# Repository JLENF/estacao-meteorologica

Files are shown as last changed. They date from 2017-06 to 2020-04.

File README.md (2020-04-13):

# estacao-meteorologica
Projeto de uma estação meteorológica autossustentável desenvolvida inicialmente para o TCC na graduação de Engenharia Eletrica - FURB.

## Informações da publicação do TCC
[Biblioteca Universitária - FURB](https://bu.furb.br/consulta/portalConsulta/recuperaMfnCompleto.php?menu=rapida&CdMFN=363865)

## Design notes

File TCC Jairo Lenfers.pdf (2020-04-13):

UNIVERSIDADE REGIONAL DE BLUMENAU - FURB CENTRO DE CIÊNCIAS TECNOLÓGICAS DO DEPARTAMENTO DE

ENGENHARIA ELÉTRICA

CURSO DE ENGENHARIA ELÉTRICA

JAIRO EVANDRO LENFERS

ESTAÇÃO METEOROLÓGICA AUTOSSUSTENTÁVEL DE CÓDIGO ABERTO

BLUMENAU

2017

JAIRO EVANDRO LENFERS

ESTAÇÃO METEOROLÓGICA AUTOSSUSTENTÁVEL DE CÓDIGO ABERTO

Trabalho de conclusão de curso apresentado ao Curso de Graduação em Engenharia Elétrica do Centro de Ciências Tecnológicas da Fundação Regional de Blumenau, como requisito parcial para a obtenção do grau de Engenheiro Eletricista.

Prof. Sérgio H. Lopes Cabral – Orientador

BLUMENAU

2017

AGRADECIMENTOS

Primeiramente, agradeço a Deus, meu Pai Celestial, por ter me dado saúde e força para

superar as dificuldades ao longa da minha jornada, e que em todos os momentos é o maior

mestre que alguém pode ter.

A minha mãe, Iracema Isensee, a minha esposa, Jessica e ao meu filho, Arthur, pelo

extenso carinho e amor incondicional cedidos a mim ao longo de minha vida, guiando-me

sempre pelos caminhos do bem e despertando em mim a sede pelo conhecimento.
À Blunix Tecnologia, meu sócio Maicon e meus colaboradores, que por muitas vezes

trabalharam exaustivamente em minha ausência para que eu tivesse tempo para me dedicar

aos estudos.

Ao meu amigo Eduardo Maes, que por diversas vezes me mostrou as vantagens do

Software Livre e sempre me ajudou com suas ideias para melhorar meus projetos.

De forma especial agradeço ao meio orientador, professor Sérgio Henrique Lopes

Cabral, que me incentivou a continuar firme nos estudos e sempre acreditou no meu potencial,

pela atenção despendida e o suporte nas orientações e correções deste trabalho.

Aos meus amigos, Frederico Marks e Rafael Bruns, que no final da graduação

resgataram a minha vontade de estudar e me ajudaram nos estudos finais de semana para que

eu pudesse concluir esta graduação.

Aos meus colegas, amigos e professores do curso de Engenharia Elétrica, no qual

estivemos juntos nesta caminhada, pela companhia e amizade em todos os momentos.

A todas as pessoas que de alguma forma contribuíram para a realização deste trabalho.

Não cruze os braços diante de uma dificuldade,

pois o maior homem do mundo morreu de braços

abertos! (Autor desconhecido)

RESUMO

O uso de estações meteorológicas está cada vez mais comum, seja para uso agrícola, para utilizar as informações coletadas para tomadas de decisões ou até mesmo para hobby. O principal problema das estações meteorológicas comerciais é sua comunicação, que muitas vezes é offline, onde somente é possível visualizar as informações no local, e quando estas informações são online, utilizam protocolos fechados desenvolvidos pela própria empresa, sem compatibilidade com outros sistemas. A utilização desta estação inicialmente será focada com destino do uso em hobby em um clube de aeromodelismo, para ter informações das condições meteorológicas em tempo real antes de se deslocar para o local, pois dependendo do tempo, fica inviável a prática. Este trabalho trata desde a aquisição dos sinais recebidos pelos sensores até a transmissão pela internet possibilitando acessar de um aplicativo móvel. Serão utilizados sensores prontos, adquiridos na internet e apresentados detalhes do funcionamento destes individualmente. A pesquisa encontra-se em código aberto, possibilitando que outras pessoas reproduzam os métodos aqui descritos em sua totalidade e consigam contribuir com a melhoria deste projeto a fim de torná-lo cada vez melhor.

Palavras-chave: Estação meteorológica. Tecnologia. Internet das coisas. Arduino. ESP8266. Eletrônica.

ABSTRACT

The use of weather stations is frequently increasing, whether for the use in agriculture, for the use of information collected for decision making or even as a hobby. The main problem of commercial weather stations is its communication, which is often offline and only accessible in loco and, when this information is online, closed protocols developed by the company itself are used, not compatible with other systems. The use of this station will initially be focused for the use of a hobby at an aeromodelling club, in order to obtain weather information in real time before heading to the location since, depending on the weather it is unfeasible to practice the hobby under certain circumstances. This study begins with the acquisition of the signals received by the sensors to the transmission through the internet, allowing access from a mobile application. It will utilize ready for use sensors acquired from the internet and the operational details of these sensors will be presented individually. The research is an open source, enabling others to reproduce the methods described herein as a whole and to contribute to the improvement of this project in order to make it even better.

Key words: Weather station. Technology. Internet of things. Arduino. ESP8266. Electronics.

LISTA DE ILUSTRAÇÕES

LISTA DE ABREVATURAS E SIGLAS

INMET – Instituto Nacional de Meteorologia

mA – mili ampéres

A - ampéres

V - volts

VRLA (Valve-regulated lead-acid)

PWM - Pulse-Width Modulation

mm – milímetros

ADC – Conversor analógico para Digital

WiFi – Rede Wireless

SUMÁRIO

### 1 INTRODUÇÃO

As alterações climáticas estão recebendo mais atenção da mídia nesses últimos tempos

e se tornou um tema habitual em jornais, sites e revistas. As informações são repassadas,

algumas de maneira equivocada devido ao sensacionalismo das emissoras de televisão e

muitas vezes sem fundamento teórico.

A necessidade de obter informações das condições climáticas remotamente em pontos

específicos e em tempo real está se tornando cada vez mais comum. Com a imensa extensão

do nosso país e sua diversidade, uma informação sobre o tempo pode mudar completamente

em distâncias curtas. Por este motivo, dificilmente é possível utilizar uma informação

coletada em uma estação meteorológica instalada em um local distante do ponto em que é

preciso medir, pois podem sofrer alterações.

Com o uso de sensores adquiridos da internet, é possível desenvolver uma estação

meteorológica com comunicação pela internet. Os sensores vão captar os dados de

temperatura, umidade relativa do ar, direção do vento, velocidade do vento e intensidade da

chuva. Os dados dos sensores são processados por um microcontrolador e estão disponíveis

para serem acessados via internet de qualquer lugar do mundo, através de um aplicativo de

mensagem instantânea em aparelhos celulares.

1.1 HISTÓRICO MUNDIAL

Diante das mudanças climáticas do planeta, tais como o aquecimento global e o

derretimento das geleiras, acelerados pela ação humana, torna-se cada vez mais difícil prever

as mudanças climáticas. Em consequência disso, tem-se o aumento dos níveis dos oceanos,

desertificação, alteração do regime das chuvas, inundações e a redução da biodiversidade [1].

Estas alterações climáticas derivadas do aquecimento global são muito graves e podem

impactar profundamente o planeta. Estudos indicam que a temperatura global subiu 5ºC nos

últimos 10 mil anos - contados desde a última geração até 10 mil anos atrás – e pode aumentar

os mesmos 5ºC nos próximos 200 anos [2], mostrando que o aquecimento global é grande o

suficiente para que uma “pessoa na rua” perceba que o tempo está realmente mais quente [3].

1.2 HISTÓRICO NACIONAL

Não muito diferente do histórico mundial com o aquecimento global, o histórico

nacional tem mostrado o mesmo problema. Com uma diversidade climática imensa, extensão

territorial de 8,5 milhões de km, motivo ao qual é conhecido por “país tropical” [4]. A

diversificação do clima depende de muitos fatores tais como umidade, correntes marítimas,

ventos, pressão atmosférica, dentre outros. A Figura 1 representa o mapa do Brasil que mostra

os climas e suas diversidades.

Figura 1 – Climas no Brasil

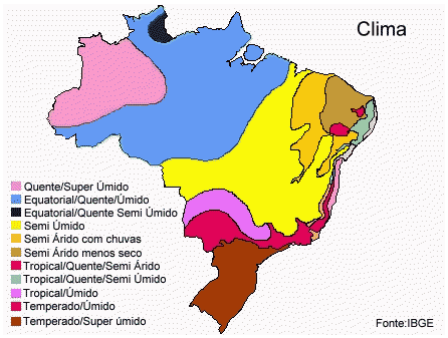
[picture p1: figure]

Fonte: IBGE [4]

Com estas diferenças climáticas entre as regiões, a informação do tempo de cada local

torna-se imprescindível para planejar a melhor colheita de determinado alimento utilizando

dados estatísticos, coletados nos anos anteriores.

Com a vinda dessas alterações pode-se notar diversos prejuízos econômicos, como a

crise que afeta diversos setores, físicos na estrutura das cidades e sociais na população. Tais

prejuízos são impostos em questão de minutos, horas, semanas mas levam anos para serem

restabelecidos.

Na região de Blumenau, Santa Catarina, tem-se históricos de chuvas abundantes em

determinados momentos, ocasionando enxurradas e enchentes. Estas chuvas ocorreram em

curto espaço de tempo e causaram bastante estragos [5]. Tais estragos poderiam ser menores

caso a população tivesse uma rede de estações meteorológicas interligadas, informando o

local exato e quantidade das chuvas. Desta forma, seria possível identificar onde a chuva está

ocorrendo exatamente e com qual intensidade. Com uma análise de dados, pode-se estipular

de onde e para onde estas chuvas estão indo e tomar certas decisões.

Muito embora haja estações meteorológicas instaladas, de modelos e diversos

fabricantes, cada uma destas estações trabalha com um protocolo diferente e não se

comunicam entre si. Além do fato de terem protocolos diferentes, muitas destas estações

passam por um tratamento de dados antes de ser apresentado ao público e algumas vezes com

certo tempo de atraso. Em alguns casos, as medições são feitas manualmente, onde um

profissional se encarrega de coletar os dados dos sensores e caso o acesso a este local esteja

comprometido, a medição também estará comprometida devido à dificuldade de chegar ao

local.

A medição exata do local em que se precisa da informação meteorológica também é

um fator decisivo. Atualmente existem no Brasil diversas estações meteorológicas instaladas,

porém, estão em locais específicos, determinados por critérios específicos do órgão que a

instalou. O Instituto Nacional de Meteorologia (INMET) possui atualmente 22 estações

meteorológicas instaladas no estado de Santa Catarina e somente duas estações estão

próximas à Blumenau conforme mostra a Figura 2.

Figura 2 – Estações meteorológicas do INMET em Santa Catarina

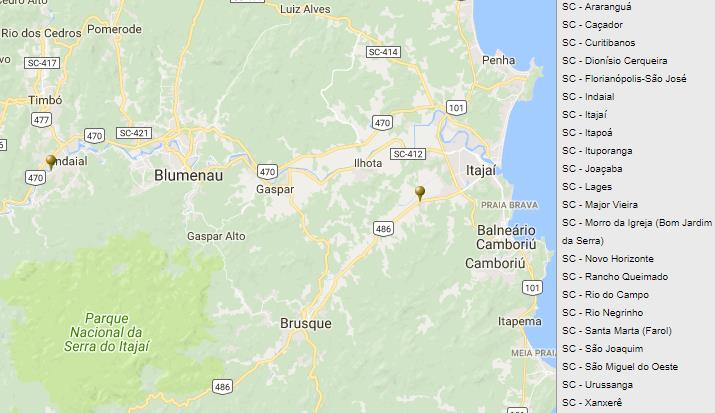
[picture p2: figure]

Fonte: INMET (2017) [6].

1.3. OBJETIVOS

1.3.1 Objetivo Geral

O objetivo geral visa pesquisar e desenvolver um projeto que atenda as

funcionalidades de uma estação meteorológica e que seja autossustentável de código aberto,

englobando o uso de sensores de alta precisão e baixo custo, aliados ao uso de tecnologias e

rede de transmissão dos dados, utilizando e mantendo todo o projeto com hardware e software

livre, para que outras pessoas possam desenvolver mais funcionalidades e agregar a este

projeto novas funções e possíveis correções.

O uso desta estação meteorológica tem a finalidade de atender a necessidade de um

clube de aeromodelismo em que faz necessário saber as informações meteorológicas em

ponto específico.

1.3.2 Objetivos Específicos

Para atingir o objetivo geral deste projeto, é preciso que alguns objetivos específicos

sejam estudados, tais como:

- O funcionamento dos sensores independentes (anemômetro, biruta,

temperatura e umidade do ar).

- Desenvolver o software do microcontrolador para receber as informações dos

sensores, processar estas informações e transmitir pela internet.

- Pesquisar a utilização de aplicativo específico para receber as mensagens com

informações coletadas pela estação meteorológica.

- Avaliar qual licenciamento utilizar para que este projeto fique disponível para

melhorias futuras e possível comercialização.

### 2 REVISÃO DE LITERATURA

Nesta revisão de literatura, serão abordados todos os itens que compõem uma estação

meteorológica tais como: o anemômetro que registra a velocidade e direção do vento, o

pluviômetro, que mede a quantidade de chuva em determinado período, sensores de

temperatura e umidade, abrigos seguros para estes sensores, dataloger que registra os dados

de vários sensores.

Como este trabalho tem o propósito de ser em código aberto, será abordado também

fundamentos do software livre e licenciamento aberto, que permite que outras pessoas possam

contribuir com este trabalho.

2.1 ANEMÔMETRO

Anemômetros são instrumentos utilizados para indicar a direção e medir a velocidade

do vento. Inspirado nos cata-ventos, eles são calibrados de forma que o total de voltas dadas

por suas pás correspondam a uma velocidade específica, ou seja, se no túnel de vento em que

foi calibrado a corrente do ar sopra a dez quilômetros por hora, e as pás giram cem vezes por

minuto, ele é programado para indicar 10 km/h sempre que o anemômetro atingir 100

rotações por minuto, e assim por diante [7].

O modelo de anemômetro mais utilizado é o modelo de copos (Anemômetro de

Robinson), mostrado na Figura 3, que utiliza três ou mais conchas montadas simetricamente e

é do tipo rotativo. A velocidade de rotação depende da velocidade do vento, não interferindo

em que direção ele chega no sensor. Geralmente utilizam um sensor magnético que conta o

número de voltas e de acordo com este número, é calculado a velocidade instantânea.

Figura 3 - Anemômetro

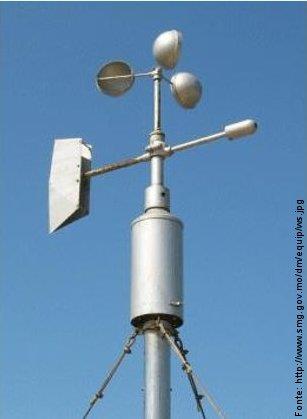
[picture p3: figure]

Fonte: CECHIN (2011). [7]

Acoplado a este anemômetro está o sensor de direção do vento. Este sensor funciona

com uma pá que mantem o “nariz” do sensor sempre apontado para frente, indicando a direção que o vento chega no sensor. É possível medir a velocidade do vento de duas formas

eletronicamente, com um potenciômetro ou com sensores magnéticos. A desvantagem de se

utilizar potenciômetro é sua vida útil e o possível arrasto que ele pode ter ao se movimentar.

2.2 PLUVIOMETRO

O pluviômetro é utilizado para medir em milímetros a quantidade de líquidos ou

sólidos, precipitados em determinado tempo e local [8].

Os modelos mais conhecidos, funcionam de modo que captam em um intervalo, a

quantidade de chuva precipitada, armazenando esta quantidade de chuva capturada em um

reservatório, conforme ilustrado na Figura 4. No final do dia ou no final da chuva, um técnico

especializado vai até o local para medir a quantidade de chuva no reservatório, funcionando

de forma totalmente manual.

Figura 4 – Pluviômetro manual

Fonte: HIDRAULIS [8].

Para entender como funciona a medição de um pluviômetro, é preciso saber como

funciona a unidade de medida de um pluviômetro.

Os pluviômetros registram as precipitações em milímetros (mm). O tanque

representado na Figura 5 possui uma área de base de 1m², se colocar 1 litro de água neste

tanque, se tem 1mm de água.

Figura 5 – Tanque demonstrando 1mm de água

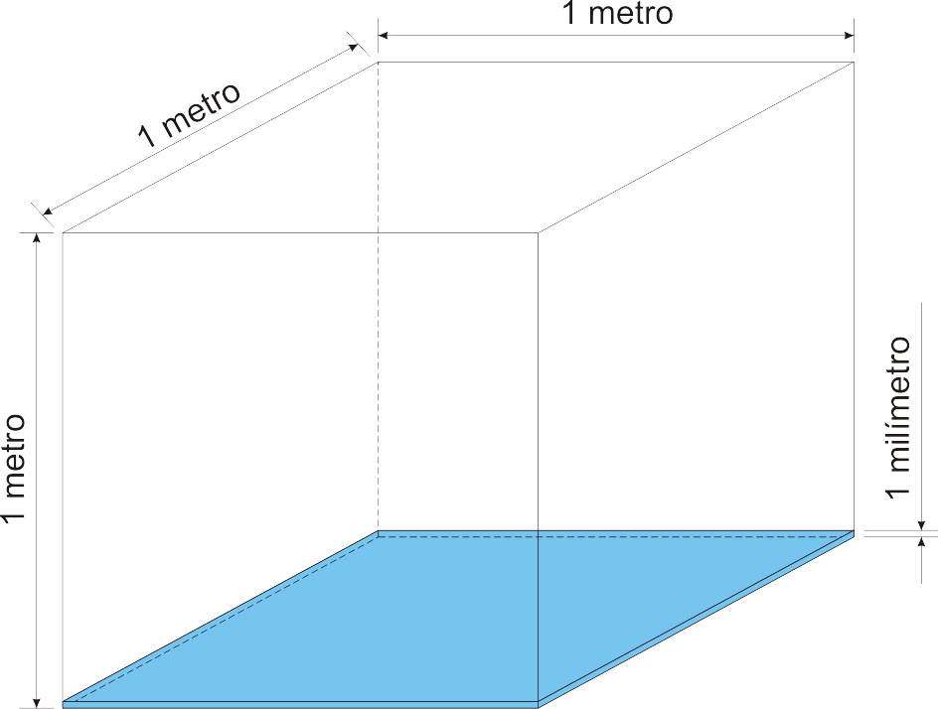
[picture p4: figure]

Fonte: MARTINS (2016). [9]

Da mesma forma é utilizado o pluviômetro manual, podemos descrever o pluviômetro

eletrônico, porém, ao invés de ter um reservatório para armazenar a quantidade de água

captada em um determinado período, ele possui um dispositivo chamado “gangorra” com dois

lados intitulado báscula, no qual, enche um pequeno reservatório e cada vez que este pequeno

reservatório enche, é enviado um pulso elétrico para o controlador efetuar a contagem [10].

De acordo com a quantidade de pulsos, é possível mensurar a quantidade de chuva precipitada

conforme mostrado na Figura 6.

Figura 6 – Pluviômetro eletrônico

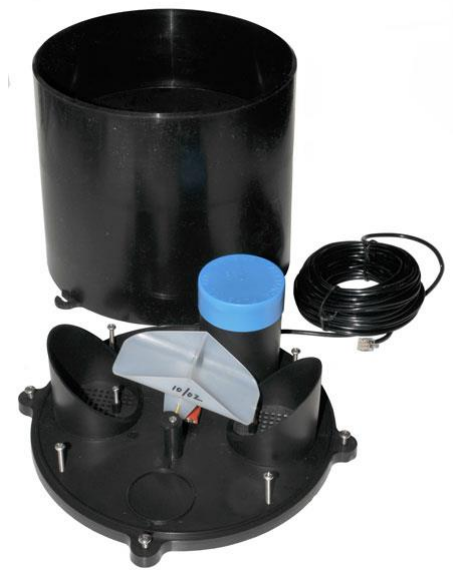
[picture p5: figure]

Fonte: BROOKE (2012). [11]

2.3 TEMPERATURA E UMIDADE DO AR

A temperatura pode ser medida com o uso de termômetros convencionais, que

fornecem um valor instantâneo desta variável. Em Meteorologia, termômetros convencionais

são do tipo liquido-em-vidro, cujo princípio de funcionamento se baseia na variação do

volume de um líquido apropriado, em resposta a uma mudança de temperatura do meio em

que está situado o instrumento. [12]

Termômetros não convencionais são os modelos que possuem sensores elétricos, que

são resistores com fio muito fino (cerca de 0,01 mm de diâmetro, cuja variação da resistência

elétrica causada pelo sensor é analisada por circuito eletrônico. A umidade relativa do ar

úmido, submetido a uma determinada temperatura, é o quociente entre a pressão parcial do

vapor e a pressão de saturação àquela temperatura. [12].

O sensor de temperatura e umidade geralmente vem em um único encapsulamento,

sendo que o mesmo sensor pode ser utilizado para efetuar as duas medições. A temperatura e

umidade do ar necessitam ser captadas por um sensor isolado e protegido, pois se o sol chegar

diretamente no sensor, pode interferir nos resultados, da mesma forma o sensor de umidade

que pode sofrer interferências com o orvalho que cai diretamente sobre ele. A umidade do ar

deve ser medida à sombra, em local ventilado e protegido da precipitação [13], motivo ao qual

é utilizado uma proteção para este sensor, mostrado na Figura 7.

Figura 7 – Sensor de temperatura e umidade

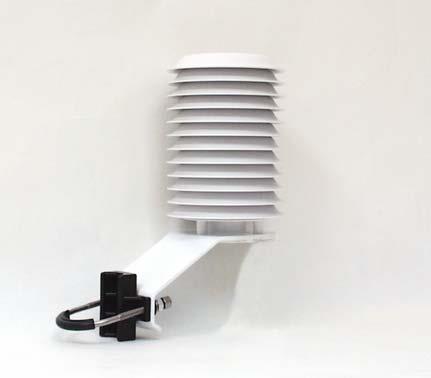
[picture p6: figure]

Fonte: CLEAN (2012). [14]

De acordo com a Organização Meteorológica Mundial (OMM) – entidade

internacional ligada à ONU que coordena as atividades operacionais na área das Ciências

Atmosféricas e estabelece normas e alturas padrões para instalação de equipamentos

meteorológicos – estes sensores de temperatura e umidade devem estar em uma altura entre

1,25 a 2,00 m acima do terreno e precisa ficar protegido [15].

2.4 DATA LOGGER

Data logger são aparelhos construídos de um micro controlador e memórias

específicas para armazenar determinados valores (Figura 8). Conseguem gravar uma série de

dados, dos diversos sensores das estações meteorológicas.

Muitas vezes, os gravadores de registros funcionam de forma offline, sem

comunicação com a internet, sendo possível visualizar as informações apenas estando no

local. Em outros casos, estas estações possuem um protocolo de comunicação próprio, onde

comunicam-se com um servidor na internet e enviam os dados de tempos em tempos para este

servidor próprio. Neste caso, as informações ficam em posse da empresa que desenvolveu esta

estação meteorológica, além de não saber se estas informações são utilizadas para outros fins,

não se tem garantia pois a empresa pode descontinuar o produto ou cobrar pelo serviço

futuramente.

Figura 8 – Data logger

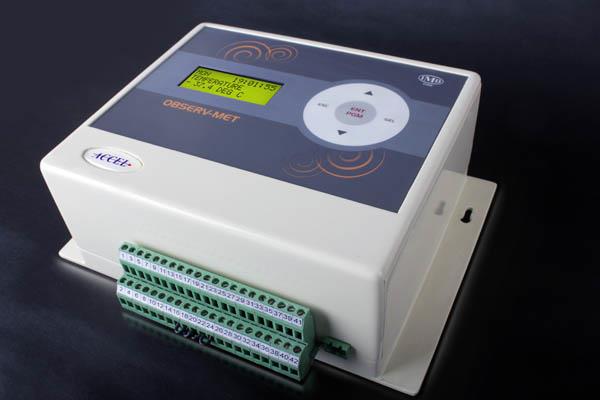
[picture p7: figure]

Fonte: ACCEL. [16]

2.5 SOFTWARE LIVRE

Um projeto, programa ou criação em geral pode ser licenciado de várias formas,

dentre elas licenciamento fechado ou aberto. Neste trabalho, é utilizado o licenciamento

baseado em código livre ou código aberto, que significa que todo seu conteúdo, seja os

códigos, desenhos, projetos, podem ser reproduzidos, copiados, alterados e comercializados.

Esse tipo de licença foi idealizado por Richard Stallman, que criou a Free Software

Foundation [17].

O software livre deve possuir quatro liberdades fundamentais e essenciais:

0 – executar o programa;

1 – acesso ao código fonte (open source = código aberto): estudar como ele

funciona e adapta-lo às suas necessidades;

2 – distribuir cópias livremente;

3 – melhorar o programa e liberar seus aperfeiçoamentos, para que toda

comunidade se beneficie.

A licença utilizada neste trabalho é a Massachusetts Institute of Technology (MIT) que

tem a seguinte característica:
- É possível usar, copiar e modificar o software pois não tem impedimento de uso o

que possibilita utiliza-lo em qualquer projeto (inclusive proprietários);

- Permite a distribuição gratuita e venda sem restrições;
- A única exigência é que o produto deve ser acompanhado com a licença.

Dentre as inúmeras vantagens do software livre, é possível ressaltar que o usuário

pode ter acesso ao código fonte do programa, contribuir com a melhoria do código ou até

mesmo entrar em contato diretamente com o desenvolvedor do software para esclarecer

dúvidas, avisar sobre falhas no sistema ou sugerir melhorias, resultando em uma agilidade no

processo de correção e melhorias. Vantagens estas que não se encontra em software

proprietários e dificilmente consegue-se entrar em contato diretamente com o desenvolvedor,

direcionando a solicitação para a equipe de suporte e que podem demorar até que cheguem ao

desenvolvedor.

Um exemplo clássico de uso em software livre é o sistema operacional Linux, gratuito,

desenvolvido por Linux Torvalds com a ajuda de milhares de programadores em todo mundo,

por se tratar de um sistema operacional de código aberto. Em contrapartida, o sistema

operacional Windows de propriedade da Microsoft ® é um sistema de código fechado, onde

somente os funcionários da empresa mantém as atualizações das funcionalidades do seu

sistema operacional.

Desta forma, utilizando o licenciamento de código aberto, este trabalho poderá sofrer

alterações e melhorarias, pois, o movimento do software livre tem como filosofia ser

colaborativo, que permite as pessoas contribuírem em áreas específicas, aprimorando a ideia

central do projeto.

### 3 PROPOSTA

Quando se fala em estações meteorológicas tem-se a ideia apenas das condições

meteorológicas de forma geral. Todavia, é possível utilizá-las para outros fins como meio de

informação do ambiente, principalmente em locais específicos. Tais necessidades são

utilizadas para trabalho ou para hobby.

A ideia de uma estação meteorológica surge a partir de um hobby praticado aos finais

de semana, o aeromodelismo, que depende da velocidade e força do vento, dependendo das

condições meteorológicas o vôo torna-se impossível. Outro exemplo são as atividades de asa

delta ou parapente, a rampa de salto é direcionada para um local e caso o vento não esteja em

direção contrária, impossibilita o vôo. Os praticantes destes esportes têm que se deslocar até o

local para a prática da atividade e muitas vezes acabam demorando para chegar, para constatar

que o vento não está de acordo. Utilizando os dados de outras estações meteorológicas, não se

consegue as informações precisas do local do vôo e mudam muito de local para local.

Na imagem seguinte, é apresentado um exemplo de local para ser instalado a estação

meteorológica. O Clube de Aeromodelismo Asas do Vale (Figura 9), permite a decolagem e

pouso dos aeromodelos que são feitos com o vento preferencialmente paralelo à pista. Caso o

vento esteja perpendicular à pista, é conhecido como vento de través e necessitam de certa

habilidade para pousar.

Figura 9 – Clube de aeromodelismo Asas do Vale em Gaspar

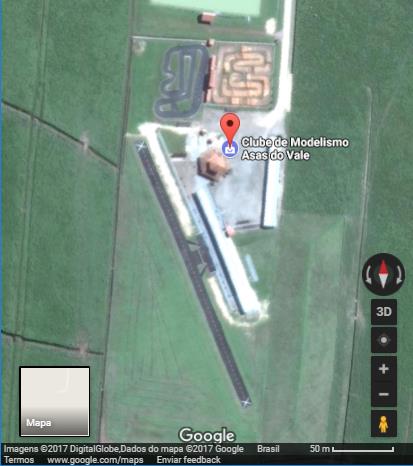
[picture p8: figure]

Fonte: GOOGLE (2017). [18]

Com base em conversas dos praticantes de aeromodelismo no clube citado,

historicamente tem-se os registros que aos sábados e domingos, o vento está paralelo à pista

somente até o horário 12h00. Geralmente a tarde o vento está de través e acontecem alguns

incidentes por conta disto. A comunicação dos sócios que estão no clube com os sócios que

estão para ir ao clube geralmente são de como está o vento e se está chovendo, conforme a

Figura 10.

Figura 10 – Exemplo troca de informações sobre o tempo local

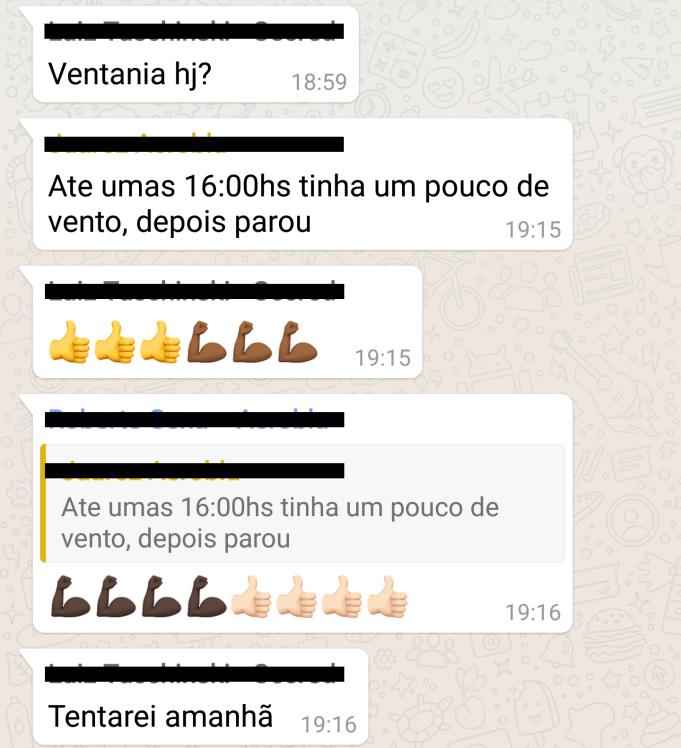
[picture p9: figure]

Fonte: O autor (2017).

Outro problema é mensurar a velocidade do vento, o que é forte para alguns pode ser

fraco para outros, dependendo da habilidade de cada piloto. Por isso é importante uma estação

meteorológica no clube para que cada piloto acompanhe em tempo real a velocidade e direção

do vento para que se sinta mais seguro em voar.

Além das informações de velocidade e direção do vento, é importante incluir um

pluviômetro para medir a quantidade de chuva que caiu no local, um sensor de temperatura e

umidade para registar as variações de temperatura, um sistema de transmissão dos dados e um

sistema de carregamento solar, para que funcione de forma autônoma. Desta forma, a estação

meteorológica poderá ser utilizada não somente nos clubes de aeromodelismo e voo livre, mas

também em outras aplicações em que requerem uma exatidão na informação de meteorologia,

tais como fazendas para ter um controle mais específico das safras.

### 4 DESENVOLVIMENTO

O desenvolvimento da estação meteorológica autossustentável se divide em vários

módulos conforme é mostrado no diagrama de blocos na Figura 11. Irá contar com vários

assuntos relacionados ao curso de Engenharia Elétrica como: geração de energia,

armazenamento de energia, análise e processamento dos sinais dos sensores, conversão de

dados, processamento em tempo real e transmissão das informações via internet para um

dispositivo móvel (celular).

Figura 11 – Diagrama de blocos

Fonte: O autor (2017).

Geração de energia: Este projeto conta com geração de energia solar com um módulo

que vai regular a tensão recebida pela placa solar e gerenciar o carregamento da bateria.

Armazenamento de energia: A estação utiliza uma bateria para que o sistema funcione

de modo offline quando a geração solar não for suficiente ou em períodos noturnos.

Análise e processamento dos sinais dos sensores: Esta estação conta com diversos

sensores de diversos tipos. Nem todos contam com a mesma interface e o mesmo protocolo de

comunicação. O projeto em questão vai abordar a forma de comunicação e protocolo destes

sensores.

Processamento em tempo real: Muitas vezes um determinado microcontrolador não

consegue atender todas as necessidades de certo projeto. Entradas e saídas são fundamentais.

A escolha entre custo e benefício é essencial. Este projeto conta com um micro controlador

que atenda estas necessidades.

Transmissão de dados via internet: Praticamente uma das partes mais importantes

deste trabalho é a comunicação online da estação meteorológica com dispositivos móveis.

4.1 MODULO SOLAR

A captação de energia é exclusivamente de forma solar, portanto a escolha de um

painel que atenda às necessidades deste projeto de forma adequada é essencial. Mediante a

medição do consumo elétrico médio do circuito, chegou-se no valor de 100mA x hora, logo,

precisa-se de um painel que forneça energia suficiente para alimentar o projeto e carregar as

baterias. O módulo solar escolhido foi o silício policristalino [19] com dimensões de

147x147mm, tensão de 12 volts e corrente nominal de 250 mA x hora por placa.

Para garantir o correto funcionamento, são utilizados quatro painéis em paralelo, para

os dias em que a geração solar não estiver no seu valor necessário. As quatro placas solares

montadas em seu suporte são mostradas na Figura 12.

Figura 12 – Placa solar

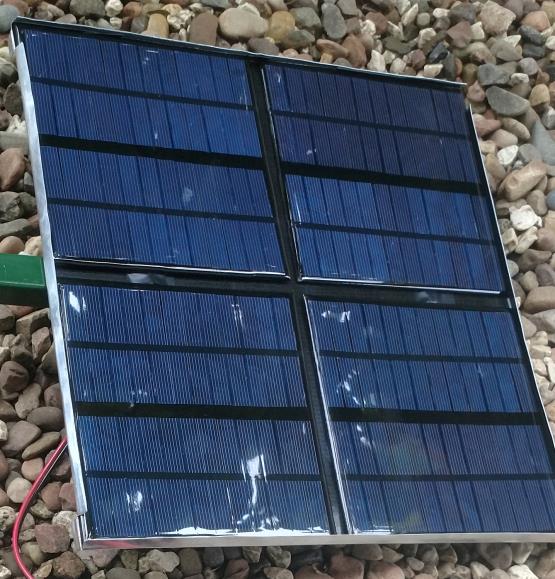
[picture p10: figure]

Fonte: O autor (2017).

4.2 CARREGADOR SOLAR

A energia captada pelas placas solares não pode ser injetadas diretamente na bateria,

para que não haja sobrecorrente e não danifique as baterias, assim, optou-se por utilizar um

gerenciador de energia solar [20], com função para carregar as baterias conforme ilustrado na

Figura 13. O modelo escolhido foi o SX01-3A com saída de 3 amperes.

Dentre suas especificações, as características abaixo são importantes para este projeto:

- Compatibilidade com bateria VRLA;
- Proteção contra sobrecarga da bateria;
- Chaveamento automático entre a célula solar e a bateria, de acordo com a

intensidade do sol;

- Controle de carregamento PWM, que garante eficiência de 3% a 16% maior que

os carregadores não-PWM;

- Proteção do painel solar contra curto circuito.

Figura 13 – Carregador solar

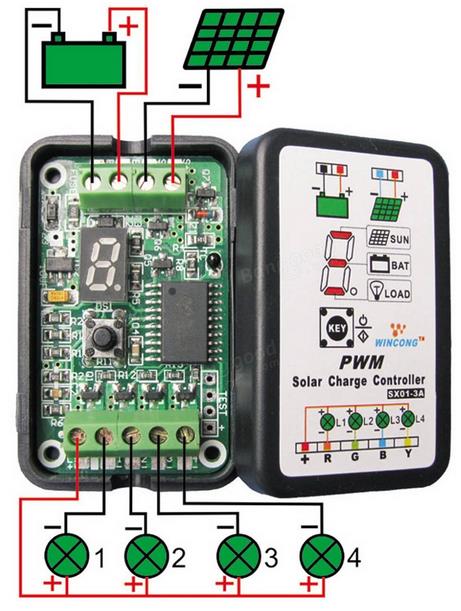
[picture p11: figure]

Fonte: ALIEXPRESS. [20]

4.3 ARMAZENAMENTO DA ENERGIA – BATERIA

A bateria escolhida para alimentar este projeto quando a geração de energia solar não

for suficiente é a bateria VRLA (Valve-regulated lead-acid), também conhecida como bateria

selada de chumbo ácido, que é livre de manutenção.

Por ser selada, pode ser utilizada em ambientes fechados pois não libera produtos

nocivos. Como a saída da célula solar é de 12v, optou-se por utilizar uma bateria de 6v. Outra

vantagem de se utilizar bateria de 6v é não precisar de um regulador externo para adequar a

tensão para o microcontrolador, uma vez que o regulador interno funciona muito bem com

esta tensão.

A capacidade escolhida foi de 12 amperes / hora, que devido ao baixo consumo do

projeto permite o uso do sistema por aproximadamente 120 horas, levando em conta um

consumo de 100mA / hora. A imagem da bateria é mostrada na Figura 14.

Figura 14 – Bateria VRLA 6v 12a

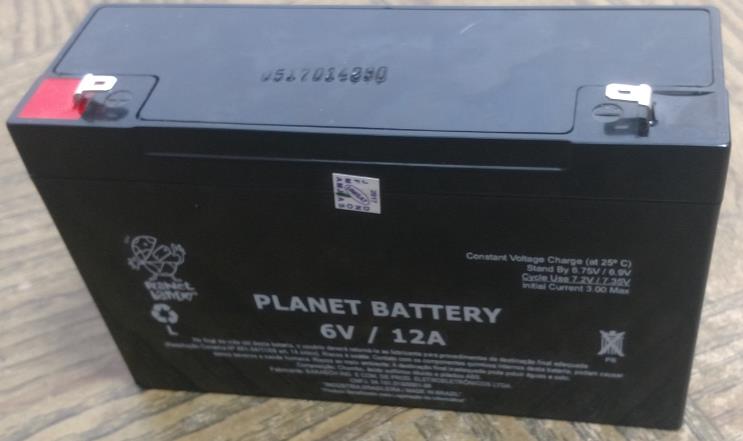
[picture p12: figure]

Fonte: O autor (2017).

4.4 ANEMÔMETRO

Este sensor possui a finalidade de medir a velocidade do vento, utilizando um sensor

magnético do tipo reed switch, que ao entrar em contato com um elemento magnético (imã),

fecha os seus contatos, deixando fluir a corrente elétrica entre seus terminais.

Para medir a velocidade do vento, é utilizado um sistema do tipo conchas, que capta a

velocidade do vento e transforma em movimento mecânico. Por um sensor magnético na base e um elemento magnético na parte superior, é possível mensurar a velocidade em que o sensor

está girando. Cada volta do sensor é enviado um pulso elétrico para o micro controlador, e

este fará a contagem. A parte interna do sensor juntamente com o sensor magnético é

mostrado na Figura 15 e a parte superior mostrando o imã é mostrado na Figura 16.

Figura 15 – Anemômetro velocidade do vento – parte interna

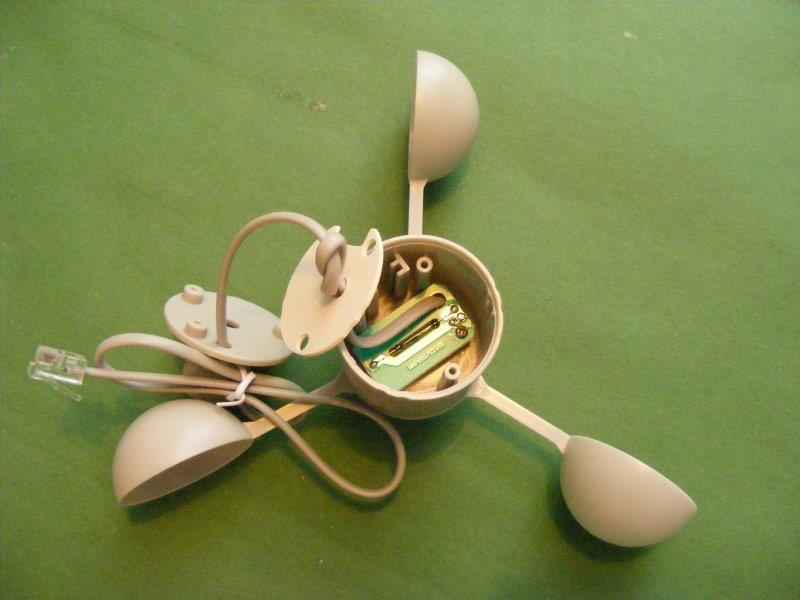
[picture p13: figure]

Fonte: PHOTOS. [21]

Na parte superior do anemômetro que mede a velocidade do vento, tem-se um

elemento magnético que ao completar uma volta completa, entra em contato as duas

extremidades do sensor magnético, enviando um pulso elétrico para o micro controlador e

assim registrando sua velocidade.

Figura 16 – Anemômetro velocidade do vento – parte superior

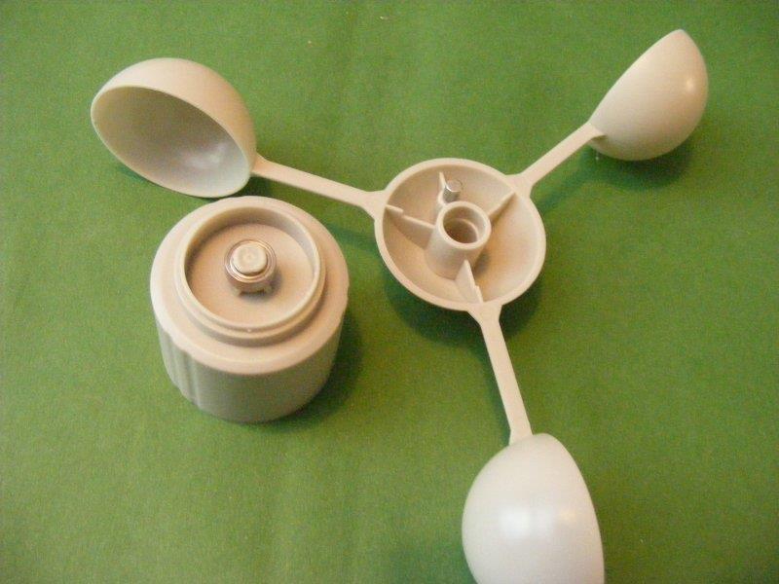
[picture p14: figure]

Fonte: PHOTOS. [21]

4.4.1 Esquema elétrico

O esquema elétrico para o funcionamento do anemômetro pode ser visto na Figura 17,

com o reed switch e um resistor de 10k push up, que mantém uma resistência com a tensão

positiva evitando que a entrada do sinal flutue entre o positivo e terra, enquanto o sensor não

está com o pulso do sinal.

Figura 17 – Esquema elétrico anemômetro

Fonte: O autor (2017).

4.4.2 Calibração

A calibração do anemômetro, consiste em uma constante definida pelo fabricante. São

efetuados testes em túneis de vento com o anemômetro e é definido o valor de uma constante

para cada modelo de anemômetro. Esta constante é multiplicada na fórmula dentro do micro

controlador para mensurar a velocidade correta do anemômetro. Pode-se aferir a velocidade

de um anemômetro utilizando outro anemômetro comercial.

4.4.3 Código

Para o funcionamento do anemômetro, foi configurado o microcontrolador para

acionar uma função (Contador Anemometro) quando houver uma interrupção na porta digital

em que o anemômetro está conectado. Cada vez que houver uma interrupção, é adicionado

um valor em uma variável (numRevsAnemometro). Após um período pré-determinado

(PERIODO_ANEMOMETRO), o microcontrolador calcula quantas voltas houve no

anemômetro | neste | período | e | multiplica | pela | constante | de | calibração

(CTE_CAL_ANEMOMETRO), para determinar a velocidade do mesmo.

4.5 BIRUTA ELETRÔNICA

Para detectar a direção do vendo, é utilizado o mesmo princípio do sensor anterior

utilizando sensores magnéticos do tipo reed switch, juntamente com um guia que manterá o

“nariz” do sensor sempre para frente indicando a direção em que o vento chega no sensor

conforme mostra a Figura 18.

Figura 18 – Biruta direção do vento

Fonte: PCE. [22]

Neste sensor é utilizado oito sensores magnéticos conforme mostrado na Figura 19 e

apenas um elemento magnético (imã) fixado na parte superior do sensor representado pelo

círculo vermelho. De acordo com a posição do ponteiro, vai entrar em contato um resistor de

determinado valor que vai mensurar a posição que se encontra atualmente.

Figura 19 - Orientação bússola

Fonte: O autor (2017).

4.5.1 Esquema elétrico

O esquema elétrico da biruta eletrônica pode ser conferido na Figura 20, com oito reed

switch ligados alimentados por uma tensão de 3,3volts em paralelo com oito resistências de

10k, e são lidos na porta analógica do micro controlador.

Figura 20 – Esquema elétrico – Biruta eletrônica

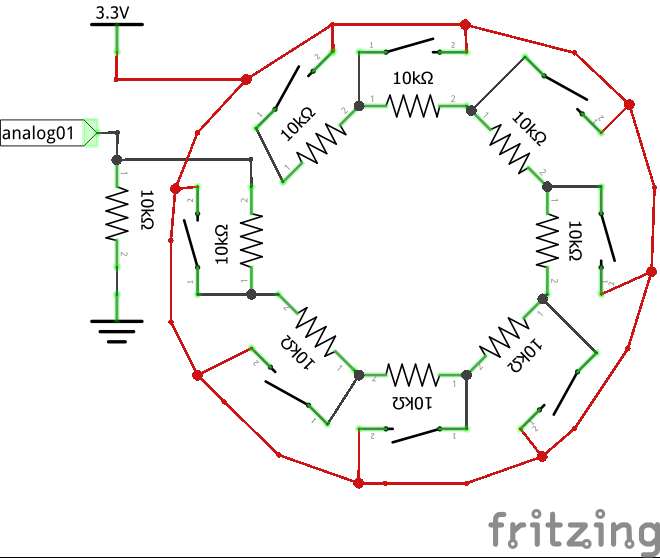
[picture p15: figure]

Fonte: O autor (2017).

4.5.2 Calibração

De acordo com a posição da biruta, o sensor vai fechar uma resistência e como estão

em série, os valores podem ir de 10k a 80k. O Norte foi arbitrado que está posicionado no

primeiro resistor de 10k e foi identificado no sensor para quando instalar no local, alinhar corretamente com o Norte. Foi utilizado um resistor externo de 10k como divisor de tensão e

foi medido a tensão de saída conforme mostra o Quadro 1 para conectar na porta do conversor

analógico / digital do micro controlador.

Quadro 1 – Relação de resistência em relação à posição do anemômetro

Direção (ângulo) | Resistencia (Ohms) | Tensão (V=3,3v, R=10k) | Valor ADC
0º - N | 10k | 1,63v | (335 a 327)
45º - NE | 20k | 1,09v | (207 a 194)
90º - E | 30k | 0,82v | (151 a 139)
135º - SE | 40k | 0,65v | (115 a 105)
180º - S | 50k | 0,54v | (91 a 84)
225º - SO | 60k | 0,47v | (77 a 72)
270º - O | 70k | 0,41v | (68 a 63)
315º - NO | 80k | 0,36v | (61 a 58)

Fonte: O autor (2017).

4.5.3 Código

Para detectar a posição da biruta, foi conectada ao microcontrolador na porta analógica

e utilizando a função “analogRead”, que converte os valores das tensões em valores digitais.

De acordo com o valor digital medido e mostrado no Quadro 1 acima, é possível detectar a

posição em que se encontra a biruta eletrônica.

4.6 SENSOR TEMPERATURA E UMIDADE DO AR

O sensor de temperatura e umidade utilizado foi o modelo DHT22 que possui saída

digital calibrada. Ele utiliza um sensor capacitivo de umidade e um termissor para medir a

temperatura do ar. Possui tamanho compacto, baixo consumo e alta precisão.

O sensor DHT22 consegue medir temperaturas de -40º a 80º Celsius, e umidade na

faixa de 0 a 100%. Sua precisão para temperatura é de 0,1º e para umidade de 0,1%. Na

Figura 21 verifica-se a pinagem de ligação deste sensor e o datasheet encontra-se no link [23].

Figura 21 – Sensor temperatura e umidade DHT22

Fonte: FILIPEFLOP (2017). [24]

4.6.1 Esquema elétrico

O sensor DHT22 possui um microcontrolador de 8bits que produz um sinal digital no

pino de dados, facilitando a comunicação com o microcontrolador. O fabricante fornece uma

biblioteca de código aberto para comunicação entre o sensor e o microcontrolador. A ligação

deste sensor é relativamente simples devido ao sinal já vir pronto, ilustrado na Figura 22.

Figura 22 – Esquema elétrico DHT22

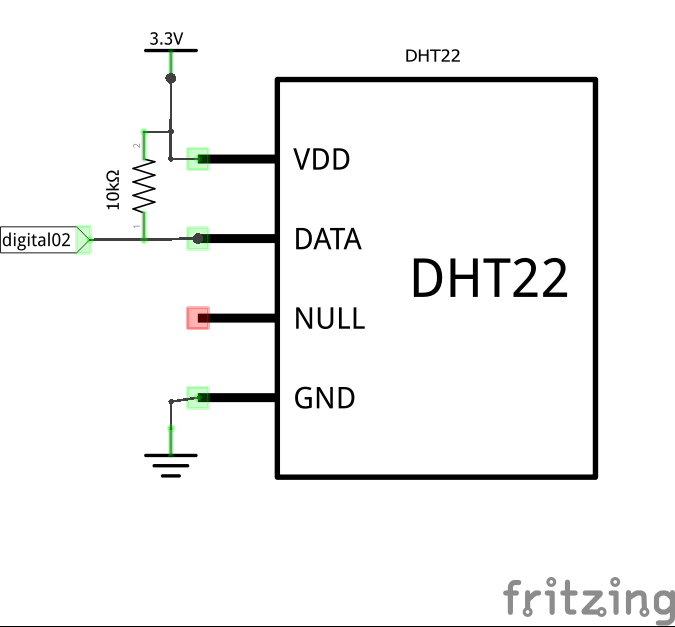
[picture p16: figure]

Fonte: O autor (2017).
4.6.2 Calibração

Por possuir um microcontrolador interno que interpreta os sinais do termissor e do

sensor capacitivo de umidade, este sensor dispensa calibração, pois contém seu encapsulamento fechado e inacessível. O único item que pode interferir na medição deste

sensor é ele ficar exposto diretamente ao sol, que pode interferir nas medições. Por isso foi

adquirido um abrigo especialmente desenvolvido para sensores de temperatura, que contem

aletas que permitem a circulação do ar sem que tenha contato direto com o sensor conforme

mostra a Figura 23.

Figura 23 – Abrigo sensor temperatura

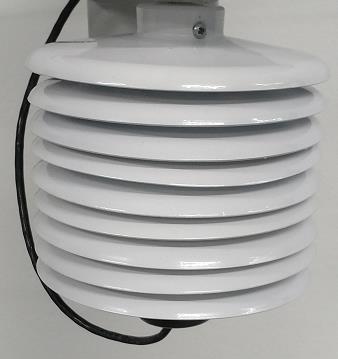
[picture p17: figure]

Fonte: O autor (2017).

4.6.3 Código

O código para funcionamento deste sensor foi fornecido pelo fabricante (DHT.h) com

todas funções necessárias para a comunicação deste sensor. Basta definir o tipo de sensor

utilizado (#define DHTTYPE DHT22), informar o pino em que o sensor está conectado ( ) e

inicializar o sensor (DHT dht(DHTPIN, DHTTYPE, 11);). Após estas configurações, foi

programado para chamar a função necessária para ler a temperatura instantânea

(dht.readTemperature()) e para ler a umidade relativa do ar (dht.readHumidity()).

4.7 PLUVIÔMETRO

O funcionamento do pluviômetro baseia-se em um funil que capta uma área e

direciona a chuva captada para uma báscula que ao receber água e transborda, movimenta-se

como uma gangorra, fechando os contatos de um sensor magnético fazendo fluir um pulso

elétrico para a entrada do microcontrolador. Cada pulso do sensor indica uma mudança de estado da báscula registrando aquela quantidade em milímetros, que é a unidade padrão de

precipitação. A Figura 24 mostra a parte superior do pluviômetro com o funil para capturar a

chuva e a Figura 25 mostra o interior de um sensor pluviométrico, com a báscula e o elemento

magnético.

Figura 24 – Parte superior do pluviômetro

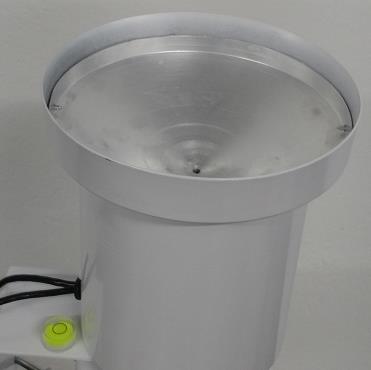
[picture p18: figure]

Fonte: O autor (2017).

Figura 25 – Interior do pluviômetro

,

Fonte: O autor (2017).

4.7.1 Esquema elétrico

O esquema elétrico para o funcionamento do pluviômetro é idêntico ao esquema

elétrico do anemômetro, com o reed switch e um resistor de 10k push up que pode ser visto na

Figura 26, que mantém uma resistência com a tensão positiva evitando que a entrada do sinal

flutue entre positivo e terra, enquanto o sensor não está com o pulso do sinal.

Figura 26 – Esquema elétrico pluviômetro

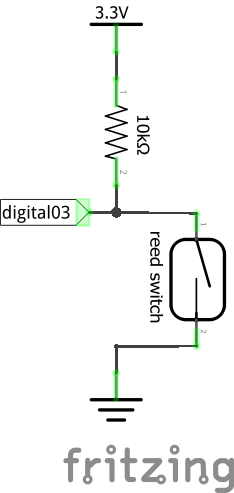
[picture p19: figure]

Fonte: O autor (2017).
4.7.2 Calibração

A calibração deste sensor conta com uma constante fornecida pelo fabricante, onde

cada báscula cheia de água muda o estado da gangorra e representa uma quantidade de chuva

captada por um pequeno reservatório. O valor fornecido pelo fabricante deste pequeno

reservatório é de 0,25mm por batida de báscula.

Pode-se aferir este valor, utilizando o método [25] descrito abaixo:

- A boca do funil que capta a chuva possui um raio de 73mm.
- Área da boca do funil = π * r² = 167,33 cm² ou 0,016733m²
- Quantidade de batidas da báscula com 500 ml de água = 67

C_b = V / ( B * A) = 0,5 l / (67 batidas * 0,016733 m²) = 0,4459 mm ≅ 0,45 mm onde C_b é a quantidade de chuva por batida de báscula, V é o volume de água

derramada, B é a contagem de batidas por cada 500 ml e A é a área da “boca” do

pluviômetro.

Para uma melhor aferição do valor medido, é utilizado um regador com a quantidade

de água citada acima, simulando uma queda de água livre igual as chuvas.

Com este experimento, podemos concluir que o volume de água por batida de báscula

é diferente do valor fornecido pelo fabricante e como este projeto foi programado para aceitar

um valor de calibração, após efetuar testes com aparelhos com maior precisão, poderá ser

alterada esta constante de calibração.

4.7.3 Código

O pluviômetro possui código semelhante ao anemômetro, onde foi configurado o

microcontrolador para acionar uma função (contadorPluviometro) quando houver uma

interrupção na porta digital em que o pluviômetro está conectado. Cada vez que houver uma

interrupção, é adicionado um valor em uma variável (numBatidasBascula). Após um período

pré-determinado (PERIODO_PLUVIOMETRO), o microcontrolador calcula quantas batidas

de báscula houve no pluviômetro neste período e multiplica pela constante de calibração

(CTE_CAL_PLUVIOMETRO), para determinar quantos milímetros choveu naquele instante.

4.8 MICRO CONTROLADOR

Este é um dos itens mais importante do projeto, o microcontrolador ESP8266 que está

incorporado em uma placa de desenvolvimento NODEMCU ESP-12E. Será executado o

programa principal que vai se comunicar com os sensores, conectar na internet e enviar os

dados para os dispositivos móveis. O código fonte completo do microcontrolador ESP8266

para funcionamento desta estação está no Anexo I.

Dentre as inúmeras vantagens de se utilizar este micro controlador, podemos citar

algumas que são muito importantes para este projeto:

-Compatibilidade com código e bibliotecas do Arduino;

-Microprocessador ARM de 32 bits;

- Suporte integrado para Rede WIFI;
- Antena WiFi embutida, já soldada na placa (livre de mal contatos);
- Compatível com IDE do Arduino;

- 10 entradas digitais GPIOs operando a 3,3V
- 1 entrada analógica GPIO a 1,8 V;
- Baixo custo;
- Tamanho reduzido da placa;
- Baixo consumo de energia;
- Temperatura de trabalho: -40 ℃ ~ +125 ℃;
- Alimentação: 4.5V ~ 9V (10VMAX), USB-powered.

A maior vantagem de utilizar este microcontrolador é sua compatibilidade com

códigos e bibliotecas do Arduino, que por sua vez permite acessar muitos exemplos de uso na

internet, dos mais variados tipos. O suporte nativo à conexões WiFi também é uma grande

vantagem, dispensando componentes externos.

As portas de entrada e saída são compartilhadas com as funções internas do micro

controlador e neste caso necessitam de uma atenção especial ao dimensionar qual entrada vai

atender qual função do projeto, conforme mostrado na Figura 27.

Figura 27 – NODEMCU ESP12-E

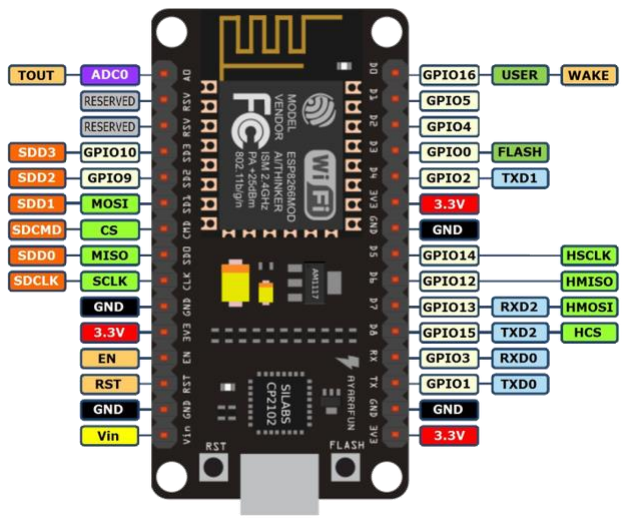
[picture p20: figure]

Fonte: TRONIXLABS. [26]

Esta placa de desenvolvimento NODEMCU contém reguladores de tensão internos e

todos componentes internos que facilitam a ligação desde o início. A tensão de trabalho do

microcontrolador é de 3,3v, motivo ao qual os sensores têm que operar nesta tensão. O

circuito de ligação dos sensores com o micro controlador pode ser visto na Figura 28.

Figura 28 – Esquema de ligação do microcontrolador com sensores

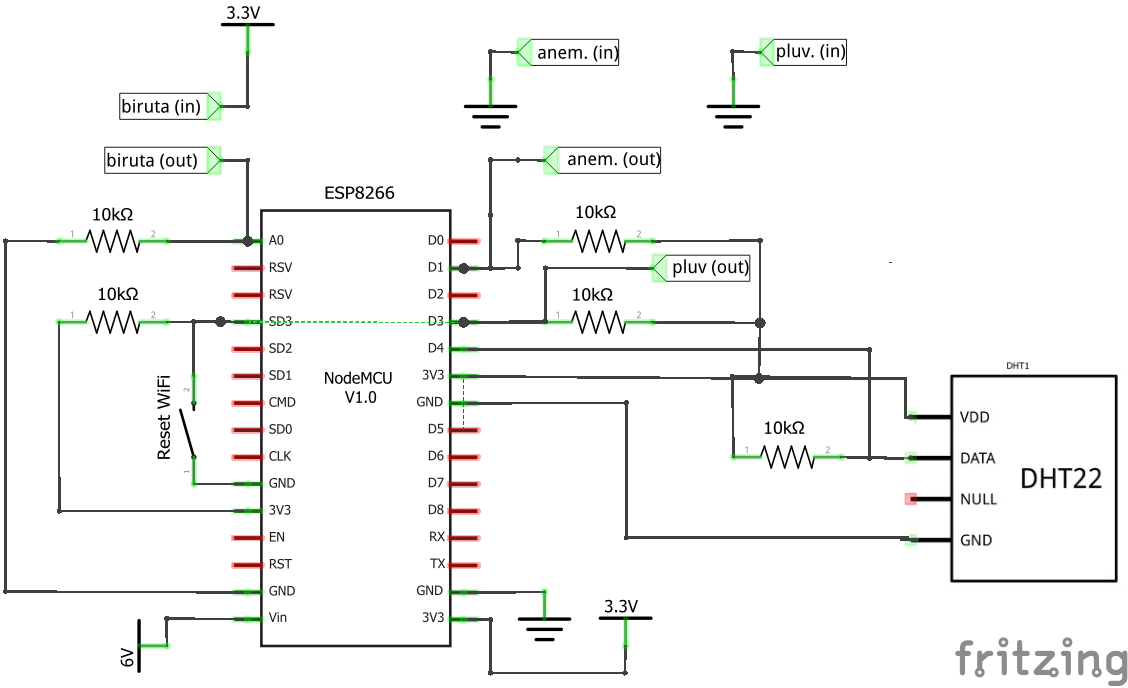
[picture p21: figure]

Fonte: O autor (2017).

O software desenvolvido para operar este microcontrolador, foi o da plataforma de

programação do Arduino. O Arduino é uma plataforma eletrônica de código aberto baseada

em hardware e software fáceis de usar.

As placas Arduino são capazes de ler entradas digitais e analógicas, além de possuir

inúmeras bibliotecas de códigos disponíveis na internet. Ao longo dos anos, o Arduino tem

sido o cérebro de milhares de projetos, desde objetos comuns até instrumentos científicos

complexos.

Uma comunidade mundial de fabricantes – estudantes, hobistas, artistas,

programadores e profissionais, se reuniram em torno desta plataforma de código aberto. Suas

contribuições somaram uma incrível quantidade de conhecimento acessível que pode ser de

grande ajuda para novatos e especialistas [27].

4.9 TELEGRAM

Este software é o responsável em fazer a comunicação entre este projeto e os

dispositivos móveis. Telegram é um serviço de mensagens instantâneas baseado na nuvem. A

vantagem de utilizar este aplicativo é a compatibilidade com vários sistemas operacionais

(Android, iOS, Windows Phone), além de compatibilidade com computadores (Windows,

Linux, OSX) [28]. Este software possui código aberto, mesmo princípio utilizado neste trabalho, que possibilita que outras pessoas estudem seu código e reproduzam caso tenham

interesse.

O serviço responsável por fazer a interface entre o Telegram e a estação meteorológica

é a possibilidade de criar bots, que são softwares programados para interagir de acordo com

comandos enviados para ele. Por exemplo, se digitar o comando /vento, o micro controlador

vai interpretar que o usuário quer saber informações sobre o vento e vai retornar para o usuário. É possível incluir bot nos grupos do Telegram, para interagir com várias pessoas de

uma vez. Mais informações sobre o funcionamento dos bots do Telegram podem ser

conferidos no link [29].

### 5 ESTUDO DE CASO

A finalidade deste projeto será para uso em um clube de aeromodelismo, para medir as

informações sobre a velocidade e direção do vento, temperatura, umidade relativa do ar e

chuva. Para alimentar este projeto, será utilizado duas placas solares de 3W cada e será

necessário dimensionar o melhor local para fixar estas placas para o melhor aproveitamento

do sol.

A posição ideal para s painéis fotovoltaicos no Brasil é voltado para o Norte. O Sol

nasce no Leste, sobe se inclinando para o Norte e se põe no Oeste conforme é mostra na

Figura 29.

Figura 29 – Percurso do sol durante o dia

Fonte: PORTAL. [30]

A melhor inclinação do painel solar é igual ao ângulo da Latitude do local onde

deseja-se instalar o painel. Neste projeto foi utilizado o Clube de Aeromodelismo Aeroblu, em

Blumenau, com Latitude -26,764, logo, a inclinação ideal do painel solar neste local será de

26º. A Latitude do local e posição do Norte é mostrado na Figura 30.

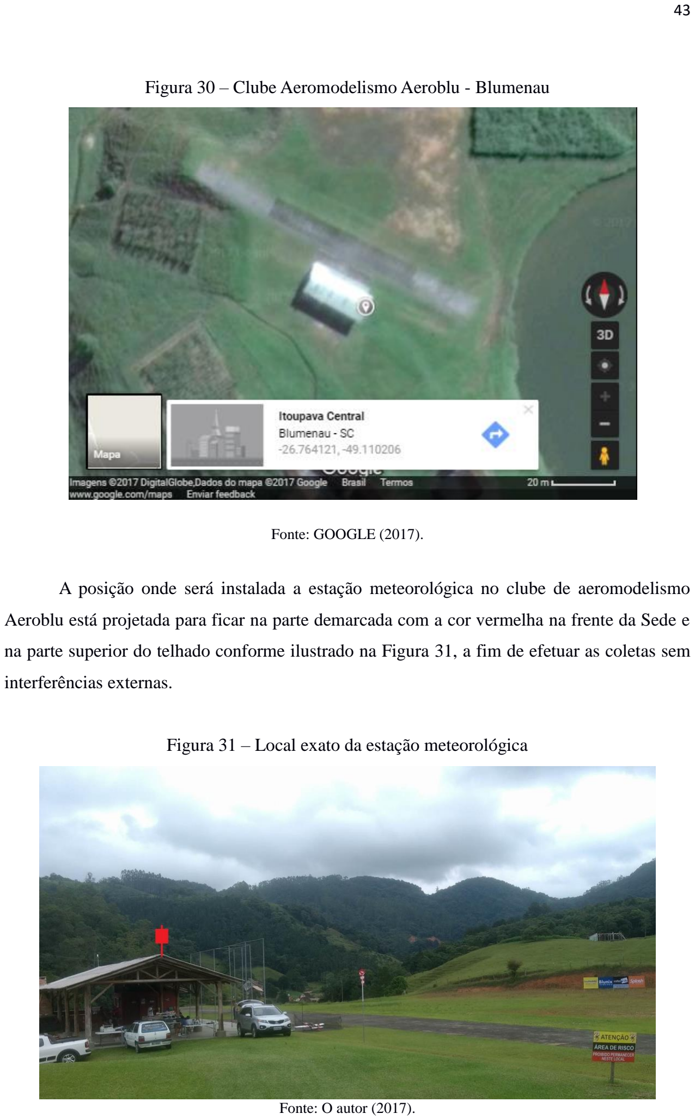
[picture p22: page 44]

Figura 30 – Clube Aeromodelismo Aeroblu - Blumenau

Fonte: GOOGLE (2017).

A posição onde será instalada a estação meteorológica no clube de aeromodelismo

Aeroblu está projetada para ficar na parte demarcada com a cor vermelha na frente da Sede e

na parte superior do telhado conforme ilustrado na Figura 31, a fim de efetuar as coletas sem

interferências externas.

Figura 31 – Local exato da estação meteorológica

Fonte: O autor (2017).

A estação meteorológica foi montada inicialmente no solo para a execução deste

projeto, programação e calibração. A posição dos sensores é fundamental para o correto

funcionamento da estação meteorológica. Na parte superior está situado o Pluviometro e

abaixo dele o abrigo do sensor de temperatura.

Logo abaixo tem-se a biruta e o anemômetro. Por último está a placa solar e a caixa

para abrir o carregador, bateria e componentes eletrônicos. A estação completa com seus

sensores pode ser visualizada na Figura 32.

Figura 32 – Estação meteorológica montada no suporte

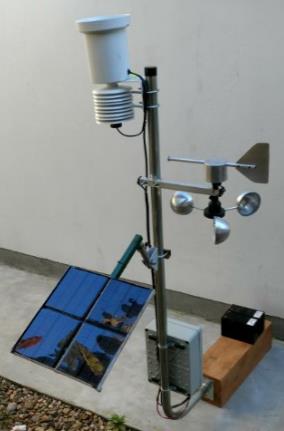
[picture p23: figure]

Fonte: O autor (2017).

Para a sua comunicação, foi registrado um bot no programa para dispositivos móveis

telegram, com o nome de Aeroblu_bot, que aceita os seguintes comandos:

/status – informa o status atual

/vento – informa a velocidade e direção do vento

/chuva – informa quantos milímetros choveu na última hora

/temp – informa a temperatura e umidade

Este bot do telegram foi inserido no grupo dos sócios do Aeroblu, para que

todos os sócios interajam com ele, solicitando informações em qualquer hora, conforme é

mostrado na Figura 33.

Figura 33 – Exemplo de utilização do sistema telegram

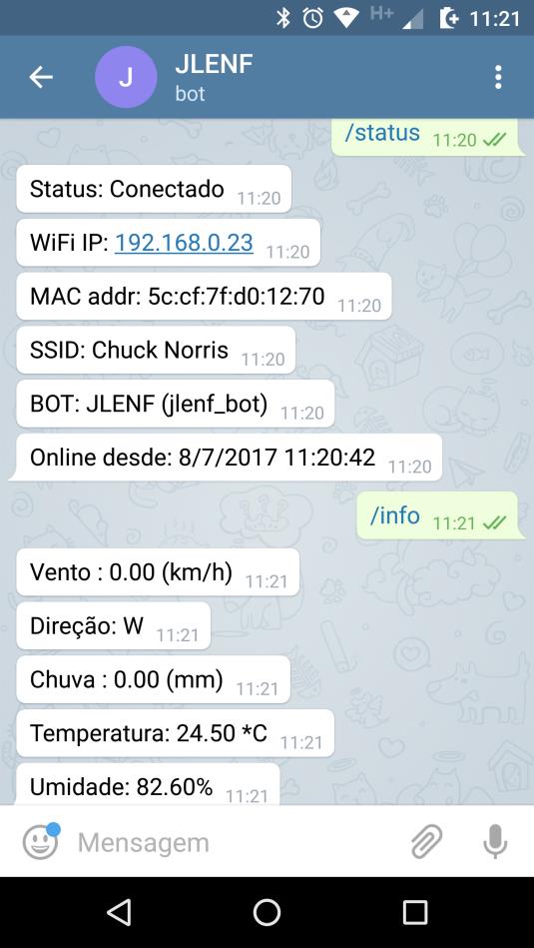
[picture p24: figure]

Fonte: O autor (2017).

O desenvolvimento contemplou todos os módulos abordados, utilizando os itens

descritos no quadro 2, com os seus respectivos valores, cotados na data em que este

documento foi escrito.

Quadro 2 – custos aproximados de construção da estação meteorológica

DESCRIÇÃO | VALOR | SITE
Placa solar 12v 3W | $ 19,30 | http://aliex.co/vp2ll
Carregador bateria solar | $ 6,86 | http://aliex.co/yua54
Bateria 6v 12A | R$ 79,00 | Unisat comercial
Anemômetro | R$ 129,95 | http://produto.mercadolivre.com.br/MLB-702511982-anemometro-digital-arduino-raspyberry-codigo-ccabo-c-10m-_JM
Biruta eletrônica | R$ 128,90 | http://produto.mercadolivre.com.br/MLB-687879199-indicador-direco-vento-c-sensor-resistivo-p-arduino-pic-_JM
Pluviômetro | R$ 149,99 | http://produto.mercadolivre.com.br/MLB-724251088-pluvimetro-automatico-estaco-meteorologica-arduino-pic-_JM
Abrigo sensor temperatura | R$ 99,90

http://produto.mercadolivre.com.br/MLB-

793409156-abrigo-alojamento-externo-sensor-

temperatura-dht22-arduino-_JM

Sensor temperatura e umidade DHT-22 | R$ 41,48 | http://proesi.com.br/catalog/product/view/id/6572/s/sensor-dht22/
ESP8266 Nodemcu | U$$ 5,19 | https://www.banggood.com/NodeMcu-Lua-WIFI-Internet-Things-Development-Board-Based-ESP8266-CP2102-Wireless-Module-p-1097112.html

Abrigo eletrônica (bateria,
carregador, esp8266) | R$ 32,00 | Elétrica Zata
Suporte ferro aço 1,20mt | R$ 45,00 | Netvis

Mão obra (suportes e
abraçadeiras) | R$ 150,00 | Airton Jung

Fonte: O autor (2017).

*Preços em 14/07/2017

### 6 ANÁLISE DO RESULTADO, CONCLUSÕES E PROPOSTAS FUTURAS

No momento tecnológico em que se vive, as estações meteorológicas estão cada vez mais comuns no dia a dia. É possível adquirir facilmente uma estação meteorológica pela

internet, que possui várias funções, tais como anemômetro, temperatura, umidade, radiação

solar, pluviômetro, dentre outras. Porém, o principal problema encontrado nas estações

meteorológicas é a sua comunicação, pois muitas vezes elas operam de modo offline, sem

contato com a internet em tempo real, ou a tecnologia é de arquitetura fechada, impedindo a

integração com outros sistemas.

Além de possibilitar a construção de uma estação meteorológica nova, é possível

utilizar as estações meteorológicas existentes, utilizando seus sensores neste projeto e

viabilizando o uso sem depender de programas de terceiros, de forma totalmente aberta.

A vantagem do uso de código aberto é a melhoria contínua onde futuramente pode ser

desenvolvido os sensores próprios, tais como o anemômetro, biruta e pluviômetro, para que

tenha um melhor rendimento e maior confiabilidade. Além dos sensores utilizados atualmente,

poderá ser incluído novos sensores, tais como radiação solar, pressão barométrica, detecção

de gases, intensidade luminosa, dentre outros. Poderá também sofrer alterações em seu código

fonte, de forma que seja mais otimizado e compatível com as tecnologias que estão surgindo,

como por exemplo, o ipv6. Novas versões deste projeto poderão ser encontradas no endereço

[31].

Atualmente, o projeto está condicionado a enviar informações da estação

meteorológica quando for solicitado via WiFi, através de aplicativo de mensagem instantânea

e devido a esta configuração, não mantém o registro dos sensores.

Como proposta futura, poderá ser desenvolvido outro método de envio dos dados para

um servidor central para o armazenamento destas informações e consequentemente

possibilitar efetuar consultas dos registros. Com estes dados armazenados, poderá ser feito um

estudo comportamental do tempo na região em que a estação está instalada, bem como uma

análise regional dos dados entre as estações. Poderá ser desenvolvido também outro método

de conexão, tal como GPRS, para utilizar em lugares onde não tenha sinal de internet WiFi.

REFERÊNCIAS

[1] FRANCISCO, Wagner de Cerqueira e. Consequências do aquecimento global. Disponível em: < http://brasilescola.uol.com.br/geografia/consequencias-do-aquecimento-global.htm>. Acesso em: 25 jun. 2017.
[2] BRASIL. Instituto Nacional de Pesquisas Espaciais (INPE). Quais as consequências do aquecimento global?. Disponível em: <http://www.inpe.br/acessoainformacao/node/483>. Acesso em: 03 fev. 2017.
[3] SATO, James Hansen and Makiko. Fraction of "Warm" Stations. Disponível em: <https://data.giss.nasa.gov/gistemp/warm_stations/>. Acesso em: 05 mar. 2017.
[4] SÓ GEOGRAFIA. Climas do Brasil. Disponível em: <http://www.sogeografia.com.br/Conteudos/GeografiaFisica/Clima/>. Acesso em: 05 mar. 2017.
[5] PREFEITURA de Blumenau. Enchentes registradas. 2017. Disponível em: <http://alertablu.cob.sc.gov.br/p/enchentes>. Acesso em: 15 jun. 2017.
[6] INSTITUTO Nacional de Meteorologia. Estação Meteorológica de Observação de Superfície Automática. Disponível em: <http://www.inmet.gov.br/portal/index.php?r=estacoes/estacoesAutomaticas>. Acesso em: 15 jun. 2017.
[7] CECHIN, Lucas. O que são anemômetros. 2011. Disponível em: <https://pt.slideshare.net/lucas_cechin/o-que-so-anemmetros>. Acesso em: 22 abr. 2017.
[8] HIDRAULIS. Pluviômetro. Disponível em: <http://www.pluviometros.com.br>. Acesso em: 22 abr. 2017.
[9] MARTINS, Samantha. Como funcionam as medições de precipitação?. 2015. Disponível em: <http://meteoropole.com.br/2015/05/como-funcionam-as-medicoes-de-precipitacao/>. Acesso em: 12 mar. 2017.
[10] MARTINS, Samantha. Dúvida do leitor: capacidade de um pluviômetro. 2016. Disponível em: <http://meteoropole.com.br/2016/04/duvida-do-leitor-capacidade-de-um-pluviometro/>. Acesso em: 22 abr. 2017.
[11] BROOKE Clarke. Components. 2012. Disponível em: <http://www.prc68.com/I/UltimeterWeatherStation.shtml>. Acesso em: 12 mar. 2017.
[12] VAREJÃO-SILVA, Mário Adelmo; INSTITUTO NACIONAL DE METEOROLOGIA, (Brasil). Meteorologia e climatologia. 2. ed. Brasília, D.F : Instituto Nacional de Meteorologia, 2001. xvi, 515p, il.
[13] TUBELIS. Antonio; NASCIMENTO, Fernando Jose Lino do. Meteorologia descritiva: fundamentos e aplicações brasileiras. São Paulo : Nobel, 1986. 374 p, il.

[14] CLEAN Enviroment Brasil. Sensor de Temperatura e Umidade Relativa do Ar. 2012. Disponível em: <http://www.clean.com.br/Blog/Post/waterlog-h-380>. Acesso em: 12 mar. 2017.
[15] GIOVELLI, Igor Ari. Sítio de Estação Meteorológica. 2007. Disponível em: <https://www.agsolve.com.br/pdf/artigos/sitio.pdf>. Acesso em: 28 abr. 2017.
[16] ACCEL System. Automatic Weather Station Data Logger: Observe-Met. Disponível em: < http://accel-systems.co.in/work/automatic-weather-station-data-logger-observe-met>. Acesso em: 28 abr. 2017.
[17] PERROTTA, Thiago Barroso. Você conhece as licenças de software livre? já está na hora de saber né?. 2013. Disponível em: < http://sejalivre.org/voce-conhece-as-licencas-de-software-livre-ja-esta-na-hora-de-saber-ne/>. Acesso em: 17 mai. 2017.
[18] GOOGLE Maps. Clube de Aeromodelismo Asas do Vale. 2017. Disponível em: <https://www.google.com.br/maps/place/Clube+de+Modelismo+Asas+do+Vale/@-26.916226,-48.9172567,680m/data=!3m1!1e3!4m5!3m4!1s0x94df237761c05c77: 0x63cd0a916e83f650!8m2!3d-26.916226!4d-48.915068>. Acesso em: 17 mai. 2017.
[19] ALIEXPRESS. 3 W 12 V Painel Solar Flexível China Placa de Silício Policristalino de Células Solares DIY 145x145mm Painel Solars Charger. Disponível em: <http://aliex.co/vp2ll>. Acesso em: 18 abr. 2017.
[20] ALIEXPRESS. 3A 6 V 12 V PWM Controlador de Luz Do Painel Solar Regulador de Carga Da Bateria para o Sistema de Painel Solar Carregador Solar Inteligente controlador. Disponível em: <http://aliex.co/yua54>. Acesso em: 18 abr. 2017.
[21] PHOTOS of the inside of the maplin & fine offset weather station modules. Disponível em: <http://www.philpot.me/weatherinsider.html>. Acesso em: 18 mai. 2017.
[22] PCE Instruments UK Ltd. Biruta. Disponível em: < http://www.industrial-needs.com/technical-data/weather-station-fws20.html>. Acesso em: 18 mai. 2017.
[23] AOSONG. Temperature and humidity module AM2302 Product Manua. 11p. Disponível em: < http://akizukidenshi.com/download/ds/aosong/AM2302.pdf>. Acesso em: 23 mar. 2017.
[24] FILIPEFLOP. Sensor temperatura e umidade DHT22. Disponível em: <http://www.filipeflop.com>. Acesso em: 23 mar. 2017.
[25] ESTAÇÃO meteorológica modular. Teste experimental do pluviômetro: Teste de quantidade de chuva por batida de báscula. Disponível em: <http://cta.if.ufrgs.br/projects/estacao-meteorologica-modular/wiki/Teste_de_quantidade_de_chuva_por_batida_de_b%C3%A1scula>. Acesso em: 23 mar. 2017.
[26] TRONIXLABS. NODEMCU ESP12-E. Disponível em: <https://tronixlabs.com.au/>. Acesso em: 18 mai. 2017.

[27] https://www.arduino.cc/en/Guide/Introduction
[28] WIKIPÉDIA. Telegram (aplicativo). Disponível em: <https://pt.wikipedia.org/wiki/Telegram_(aplicativo)>. Acesso em: 23 mar. 2017.
[29] BOTS: An introduction for developers. Disponível em: <https://core.telegram.org/bots>. Acesso em: 23 mar. 2017.
[30] PORTAL Solar. A posição ideal para os seus painéis fotovoltaicos no Brasil é voltado para o Norte. Disponível em: <http://www.portalsolar.com.br/a-melhor-direcao-do-painel-solar-fotovoltaico.html>. Acesso em: 18 mai. 2017.
[31] LENFERS, Jairo. Estação meteorológica. 2017. Disponível em: <https://github.com/JLENF/estacao-meteorologica. Acesso em 2017. Acesso em: 10 jun. 2017.

ANEXO 1 – CÓDIGO MICROCONTROLADOR ESP8266

/*
**********************************************************************
* | Estação meteorológica auto sustentável em código aberto | *
* | Projeto desenvolvido no TCC de Engenharia Elétrica - FURB | *
* | Para obtenção do título de Engenheiro Eletricista | *
* | Data: 12/03/2017 | *
* | Ultima alteração: 09/07/2017 | *
* | Changelog: | *
* | - incluído função para mostrar a data e hora atual (/hora) | *
* | - incluído função para mostrar temp. e umid. máximas (/max) | *
* | - incluído função para mostrar pluviometro por uma hora (/chuva) *
* | *
* | Este projeto é de código aberto e utiliza partes de código | *
* | de outros projetos de código aberto: | *
* | - http://cta.if.ufrgs.br | *
* | - http://air.imag.fr/mediawiki/index.php/SEN-08942 | *
* | - https://github.com/PaulStoffregen/Time | *
* | - https://github.com/esp8266/Arduino/issues/313 | *
* | *
* | Bibliotecas necessárias: | *
* | - https://github.com/arduino-libraries/NTPClient | *
* | - https://github.com/PaulStoffregen/Time | *
* | - https://github.com/adafruit/DHT-sensor-library | *
* | - https://github.com/Gianbacchio/ESP8266-TelegramBot | *
* | *
* | Para compilar o ESP8266 no Arduino, cole a URL abaixo | *
* | em Arquivo -> Preferências -> URL: | *
* | http://arduino.esp8266.com/stable/package_esp8266com_index.json | *
* | *
* | Você pode contribuir com este projeto e acompanhar seu | *
* | desenvolvimento no endereço oficial do projeto: | *
* | http://www.github.com/jlenf/ | *
* | Autor: Jairo Lenfers - jairolenfers@gmail.com | *
* | *
********************************************************************** */

// Bibliotecas externas
#include <ESP8266WiFi.h>

#include <WiFiClientSecure.h> #include <ESP8266TelegramBOT.h> #include <DHT.h>

#include <NTPClient.h>

#include <WiFiUdp.h>

#include <TimeLib.h>

// Definição de constantes de calibração
#define CTE_CAL_ANEMOMETRO 0.9011 | // 1 rev/segundo | = 0.9011 kph

#define CTE_CAL_PLUVIOMETRO 0.4459 | // 1 batida = 0.4459 mm

#define DHTTYPE DHT22 | // Modelo do sensor de temperatura

// Definição de constantes de WiFi
const char* ssid = "rede_wifi"; // Nome da rede WiFi
const char* password = "*******************"; // Senha da rede WiFi

// Definição de constantes do Telegram BOT
// Utilize o BOT Father para criar seu token: https://core.telegram.org/bots #define BOTtoken "123456789:*************************" // Token do BOT
#define BOTname "BOTNAME" // Nome do BOT

#define BOTusername "user_bot" // usuário do BOT

String numero_tel = "12345678"; // Código telefone que recebe primeira msg (ver na serial)
// Período entre as medidas em milisegundos
#define PERIODO_ANEMOMETRO | 5000

#define PERIODO_DIR_VENTO | 5000

#define PERIODO_PLUVIOMETRO 5000

// Pinos para conexão com o ESP8266
#define ANEMOMETRO_PIN | 5 | // Digital D1 Nodemcu

#define PLUVIOMETRO_PIN | 4 | // Digital D2 Nodemcu

#define DIR_VENTO_PIN | A0 | // Analog A0 Nodemcu

#define DHTPIN 2 | | // Digital D4 Nodemcu

// Variáveis globais
float tempf ,humf, temp_maxf, hum_maxf;
String temp, hum, temp_max, hum_max, data_temp_max, data_hum_max; int16_t utc = -3; //UTC -3:00 Brasil
String uptime_data;
String uptime_hora;
String atual_data;
String atual_hora;
String clientMac = "";
unsigned char mac[6];
int Bot_mtbs = 1000;
long Bot_lasttime;
bool Start = false;
const long intervalo_alerta = 60000; // = 60 segundos
double volume_minutos[60]; // volume pluviômetro últimos 60 minutos int ult_minuto = 0; // qual o ultimo minuto antes de mudar de estado double volume_hora_mm;

// Variáveis para incrementação
volatile int numRevsAnemometro = 0; volatile int numBatidasBascula = 0;

// Variáveis para realização do polling unsigned long proximaMedidaAnemometro = 0; unsigned long proximaMedidaPluviometro = 0;
unsigned long proximaMedidaDirVento = 0;
unsigned long tempo = 0;
unsigned long previousMillis = 0; // diferenca entre tempo de aquisição da temp. const long interval = 2000;

// Variáveis para converter para String para mostrar no Telegram
String S_vel_med;
String S_local_ip;
String S_ssid;
String S_direcao;
String S_volume_mm;
String S_volume_hora_mm;
String S_bot_name;
String S_bot_username;

// Inicialização gerais
DHT dht(DHTPIN, DHTTYPE, 11); // 11 works fine for ESP8266 TelegramBOT bot(BOTtoken, BOTname, BOTusername);
WiFiUDP ntpUDP;
NTPClient timeClient(ntpUDP, "a.st1.ntp.br", utc*3600, 60000);

// Direção do vento, valores de leitura para diferenciar cada direção: // int adc[8] = {26, 45, 77, 118, 161, 196, 220, 256};
int adc[8] = {104, 180, 308, 472, 644, 784, 880, 1024};
// Relação entre os valores analógicos lidos e o que eles representam // Para facilitar pode-se usar a biblioteca String
char *direcoes[8] = {"W","NW","N","SW","NE","S","SE","E"};
int direcaoInicial = 0;

void setup() {
pinMode(LED_BUILTIN, OUTPUT); digitalWrite(LED_BUILTIN, HIGH); Serial.begin(9600);
dht.begin(); // inicia o sensor de temperatura

// Definição de entradas e saídas
pinMode(ANEMOMETRO_PIN, INPUT_PULLUP);
pinMode(PLUVIOMETRO_PIN, INPUT_PULLUP); attachInterrupt(digitalPinToInterrupt(ANEMOMETRO_PIN), contadorAnemometro, FALLING);
attachInterrupt(digitalPinToInterrupt(PLUVIOMETRO_PIN), contadorPluviometro, FALLING);

// Conecta na rede WiFi
Serial.println();
Serial.println();
Serial.print("Conectando na rede ");
Serial.println(ssid);
WiFi.begin(ssid, password);
while (WiFi.status() != WL_CONNECTED) { // Enquanto tenta conectar, coloca um caracter . na serial
delay(500);
Serial.print(".");
}
Serial.println("");
Serial.println("WiFi conectado");
Serial.println(WiFi.localIP()); | // Mostra o ip que adquiriu
WiFi.macAddress(mac); | // MAC Address que adquiriu
clientMac += macToStr(mac);

bot.begin(); // Inicia o bot telegram
Serial.println("BOT started");
pinMode(2, OUTPUT); // led do wifi conectado bot.sendMessage(numero_tel,"Estação 01 - Conectada!",""); // envia mensagem para numero padrao dizendo que ligou

// Inicia NTP
delay(2000);
timeClient.begin();
timeClient.update();
setSyncProvider(&ntpSyncProvider);

// Pega a data e hora que ligou o sistema delay(2000);
uptime_data_hora();

// Converte as variaveis para String para mostrar no Telegram S_local_ip = WiFi.localIP().toString();
S_ssid = String(ssid);
S_bot_name = String(BOTname);
S_bot_username = String(BOTusername); S_bot_name.concat(" (");
S_bot_name.concat(S_bot_username); S_bot_name.concat(")");

void loop() { // Loop principal

// Verifica se tem requisição do telegram
if (millis() > Bot_lasttime + Bot_mtbs) | {
bot.getUpdates(bot.message[0][1]); | // Chama a API GetUpdates
Bot_ExecMessages(); | // Responde as mensagens com ECHO
Bot_lasttime = millis();

// Realizando o polling
tempo = millis();

if (tempo >= proximaMedidaAnemometro) {
Serial.print("Vento (km/h): ");Serial.println(calcVelocidadeVento(), 2); proximaMedidaAnemometro = tempo + PERIODO_ANEMOMETRO;
if (tempo >= proximaMedidaDirVento) {
Serial.print("Direcao: ");Serial.println(calcDirecaoVento()); proximaMedidaDirVento = tempo + PERIODO_DIR_VENTO;

}
if (tempo >= proximaMedidaPluviometro) {
Serial.print("Chuva (mm): ");Serial.println(calcQuantidadeChuva(), 3); proximaMedidaPluviometro = tempo + PERIODO_PLUVIOMETRO;
}
gettemperature(); // Fica atualizando a temperatura para variaveis globais }

void uptime_data_hora() { // Funcao para pegar data e hora que o sistema ligou time_t t = now();
uptime_hora = String(hour(t));
uptime_hora.concat(":");
uptime_hora.concat(minute(t)); uptime_hora.concat(":");
uptime_hora.concat(second(t)); uptime_data = String(day(t)); uptime_data.concat("/");
uptime_data.concat(month(t)); uptime_data.concat("/");
uptime_data.concat(year(t)); uptime_data.concat(" ");
uptime_data.concat(uptime_hora);
}

void atual_data_hora() { // Funcao para pegar a data e hora atual time_t a = now();
atual_hora = String(hour(a));
atual_hora.concat(":");
atual_hora.concat(minute(a)); atual_hora.concat(":");
atual_hora.concat(second(a)); atual_data = String(day(a)); atual_data.concat("/");
atual_data.concat(month(a)); atual_data.concat("/");
atual_data.concat(year(a)); atual_data.concat(" ");
atual_data.concat(atual_hora);
}

String macToStr(const uint8_t* mac){ // Função para pegar o MAC Address e converter em String
String result;
for (int i = 0; i < 6; ++i) {
result += String(mac[i], 16); if (i < 5)
result += ':';
}
return result;
}

time_t ntpSyncProvider() { // Função para o NTP return timeClient.getEpochTime();
}

void contadorAnemometro() { // Funções de callback de interrupção anemometro numRevsAnemometro++;
Serial.println("============ | INTERRUPCAO | ANEMOMETRO =================="); //
DEBUG para serial quando recebeu interrupcao
}

void contadorPluviometro() { // Funções de callback de interrupção pluviometro numBatidasBascula++;
Serial.println("============ | INTERRUPCAO | PLUVIOMETRO =================="); //
DEBUG para serial quando recebeu interrupcao
double calcVelocidadeVento(){ // Função para converter as aquisições com o periodo informado
double velocidadeMedia;

velocidadeMedia = numRevsAnemometro; velocidadeMedia *= 1000.0*CTE_CAL_ANEMOMETRO; velocidadeMedia /= PERIODO_ANEMOMETRO;
// Resetando contador de pulsos do anemometro numRevsAnemometro = 0;
S_vel_med = String(velocidadeMedia); return velocidadeMedia;
}

char* calcDirecaoVento() { // Função para transformar os valores analogicos em direções do vento
int valor, x;
valor = analogRead(DIR_VENTO_PIN);
for (x = 0; x < 8; x++) {
if (adc[x] >= valor)
break;
}
// Ajustando direção inicial
x = (x + direcaoInicial) % 8; S_direcao = String(direcoes[x]); return direcoes[x];
}

void pluv_ultima_hora(double vol_5s){ // Funcao para incluir os valores do pluviometro na última hora
time_t u = now();
int now_min = minute(u);
if (ult_minuto != now_min){
volume_minutos[now_min] = 0; // inicia uma nova contagem no minuto atual quando ele chegar
ult_minuto = now_min;
}
volume_minutos[now_min] += vol_5s;
}

void calc_pluv_ultima_hora(){ // Função para somar todos os valores da última hora do pluviometro
int x;
volume_hora_mm = 0;
for (x = 0; x < 60; x++) {
volume_hora_mm += | volume_minutos[x];
Serial.print(x);Serial.print(" ");Serial.println(volume_minutos[x]); | //
DEBUG
}
S_volume_hora_mm = String(volume_hora_mm);
}

void zera_pluv_ultima_hora(){ // Função para zerar os valores do pluviometro da última hora
int x;
volume_hora_mm = 0;
for (x = 0; x < 60; x++) { volume_minutos[x] = 0;
}
S_volume_hora_mm = String(volume_hora_mm);
}
double calcQuantidadeChuva(){ // Função para calcular a quantidade de chuva instantânea
double volumeMedio;
volumeMedio = numBatidasBascula;
volumeMedio *= 1000.0*CTE_CAL_PLUVIOMETRO;
volumeMedio /= PERIODO_PLUVIOMETRO;
numBatidasBascula = 0;
pluv_ultima_hora(volumeMedio); // envia para funcao para calcular a media da ultima hora
S_volume_mm = String(volumeMedio); // transforma em String para funcionar no Telegram
return volumeMedio;

}

void gettemperature() { // Função para pegar os dados de temperatura e umidade do sensor DHT22
// Espera dois segundos entre as medicoes.
// se a diferenca do tempo entre o tempo atual e o ultimo tempo que leu
// o sensor for maior que o intervado setado, vai ler o sensor
// Funciona melhor que delay
unsigned long currentMillis = millis();
if(currentMillis - previousMillis >= interval) {
// salva o ultimo tempo que leu o sensor
previousMillis = currentMillis;
humf = dht.readHumidity(); | // Faz a leitura da Umidade (percentual)
tempf = dht.readTemperature(); | // Faz a leitura da Temperatura
if (isnan(humf) || isnan(tempf)) { // Função para detectar se houve erro na leitura do sensor
Serial.println("Falha ao ler o sensor DHT22!");
return;
}else{
temp = | String(tempf);
hum = | String(humf);
if (tempf >= temp_maxf){ // Detecta se a temperatura é maior que a maxima registrada
atual_data_hora(); // Se for, anota a data e hora que ocorreu data_temp_max = atual_data;
temp_max = String(tempf);
temp_maxf = tempf;
}
if (humf >= hum_maxf){ // Detecta se a umidade é maior que a maxima registrada
atual_data_hora(); // Se for, anota a data e hora que ocorreu data_hum_max = atual_data;
hum_max = String(humf);
hum_maxf = humf;
}
}
}

void Bot_ExecMessages() { // Função que processa as mensagens do telegram
for (int i = 1; i < bot.message[0][0].toInt() + 1; i++) | {
bot.message[i][5]=bot.message[i][5].substring(1,bot.message[i][5].length()); Serial.println(bot.message[i][5]); // DEBUG temporario - para saber o que ele esta recebendo, para saber como tratar
if (bot.message[i][5] == "status") {
bot.sendMessage(bot.message[i][4], "Status: Conectado", ""); bot.sendMessage(bot.message[i][4], "WiFi IP: " + S_local_ip, ""); bot.sendMessage(bot.message[i][4], "MAC addr: " + clientMac, ""); bot.sendMessage(bot.message[i][4], "SSID: " + S_ssid, ""); bot.sendMessage(bot.message[i][4], "BOT: " + S_bot_name, ""); bot.sendMessage(bot.message[i][4], "Online desde: " + uptime_data, "");
}
if (bot.message[i][5] == "vento") {
bot.sendMessage(bot.message[i][4], "Vento : " + S_vel_med + " (km/h)", ""); bot.sendMessage(bot.message[i][4], "Direção: " + S_direcao, "");
}
if (bot.message[i][5] == "chuva") {
calc_pluv_ultima_hora();
bot.sendMessage(bot.message[i][4],"Chuva (instantânea): " + S_volume_mm + " (mm)","");
bot.sendMessage(bot.message[i][4],"Chuva (ultima hora): " + S_volume_hora_mm + " (mm)","");
}
if (bot.message[i][5] == "zera") {
zera_pluv_ultima_hora();
calc_pluv_ultima_hora();
bot.sendMessage(bot.message[i][4],"Informações da chuva na última hora zeradas!","");

bot.sendMessage(bot.message[i][4],"Chuva (ultima hora): " + S_volume_hora_mm + " (mm)","");
}
if (bot.message[i][5] == "temp") {
gettemperature();
bot.sendMessage(bot.message[i][4],"Temperatura: " + temp + " *C",""); bot.sendMessage(bot.message[i][4],"Umidade: " + hum + "%","");
}
if (bot.message[i][5] == "max") {
gettemperature();
bot.sendMessage(bot.message[i][4],"Temperatura (max): " + temp_max + " *C","");
bot.sendMessage(bot.message[i][4],"Data: " + data_temp_max,""); bot.sendMessage(bot.message[i][4],"--------------------",""); bot.sendMessage(bot.message[i][4],"Umidade (max): " + hum_max + "%",""); bot.sendMessage(bot.message[i][4],"Data: " + data_hum_max,"");
}
if (bot.message[i][5] == "info") {
bot.sendMessage(bot.message[i][4], "Vento : " + S_vel_med + " (km/h)", ""); bot.sendMessage(bot.message[i][4], "Direção: " + S_direcao, ""); bot.sendMessage(bot.message[i][4],"Chuva : " + S_volume_mm + " (mm)",""); bot.sendMessage(bot.message[i][4],"Temperatura: " + temp + " *C",""); bot.sendMessage(bot.message[i][4],"Umidade: " + hum + "%","");
}
if (bot.message[i][5] == "conf") {
numero_tel = bot.message[i][4]; bot.sendMessage(bot.message[i][4],"Configurado alerta para mostrar aqui",""); }
if (bot.message[i][5] == "hora") {
atual_data_hora();
bot.sendMessage(bot.message[i][4],"Data/Hora atual (ntp -3):",""); bot.sendMessage(bot.message[i][4],atual_data,"");
}
if (bot.message[i][5] == "start") { // mensagem padrão quando adiciona o bot, mostrando as funções
String wellcome = "Estação Meteorológica WiFi";
String wellcome1 = "/status : informa o status atual";
String wellcome2 = "/vento : velocidade e direção do vento";
String wellcome3 = "/chuva : milimetros que choveu última hora"; String wellcome4 = "/zera : zerar informações da chuva na última hora"; String wellcome5 = "/temp : temperatura e umidade";
String wellcome6 = "/max : mostra temperatura e umidade maximas"; String wellcome7 = "/info : mostra todas informações dos sensores"; String wellcome8 = "/conf : configura onde vai mostrar os alertas"; String wellcome9 = "/hora : mostra a hora atual do sistema (ntp)"; bot.sendMessage(bot.message[i][4], wellcome, ""); bot.sendMessage(bot.message[i][4], wellcome1, ""); bot.sendMessage(bot.message[i][4], wellcome2, ""); bot.sendMessage(bot.message[i][4], wellcome3, ""); bot.sendMessage(bot.message[i][4], wellcome4, ""); bot.sendMessage(bot.message[i][4], wellcome5, ""); bot.sendMessage(bot.message[i][4], wellcome6, ""); bot.sendMessage(bot.message[i][4], wellcome7, ""); bot.sendMessage(bot.message[i][4], wellcome8, ""); bot.sendMessage(bot.message[i][4], wellcome9, ""); Start = true;
}
Serial.println(bot.message[i][4]);
}
bot.message[0][0] = ""; // todas mensagens foram respondidas }

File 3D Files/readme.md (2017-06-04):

# 3D Files
Arquivos que fazem parte da estação meteorológica para serem impressos na impressora 3D

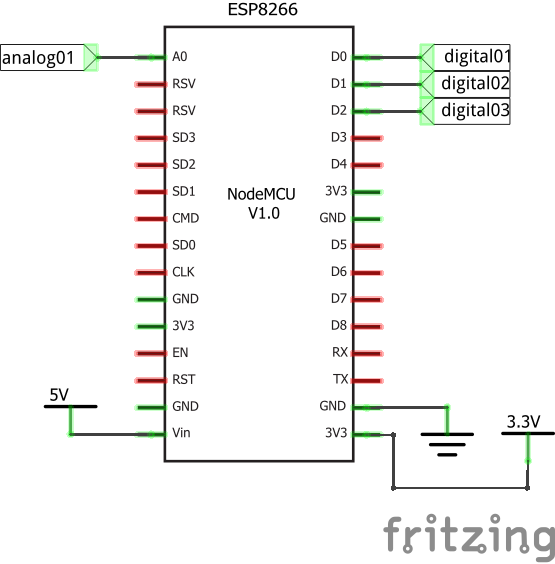
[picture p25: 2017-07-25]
Esquema eletrico/nodemcu_Esquemático.png

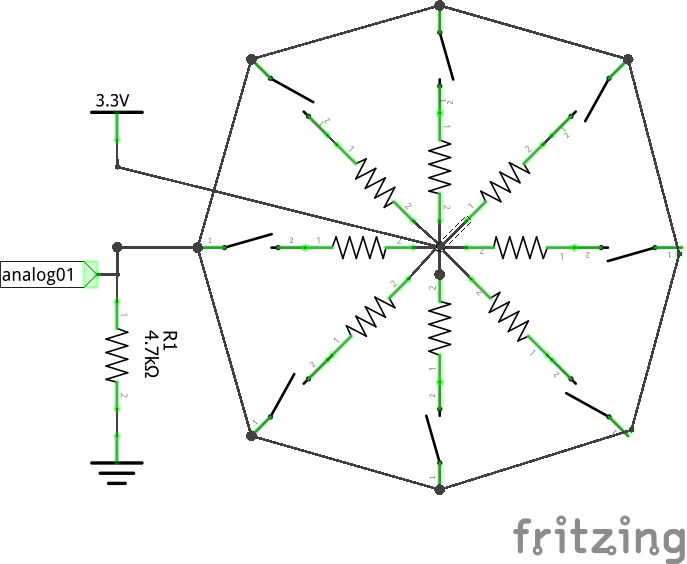
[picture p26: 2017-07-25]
Esquema eletrico/biruta_Esquemático.png

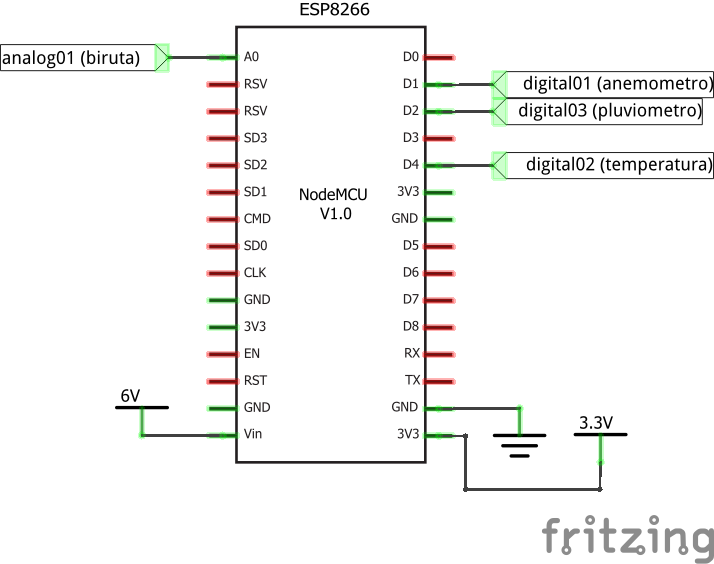
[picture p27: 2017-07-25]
Esquema eletrico/nodemcu_Esquemático2.png

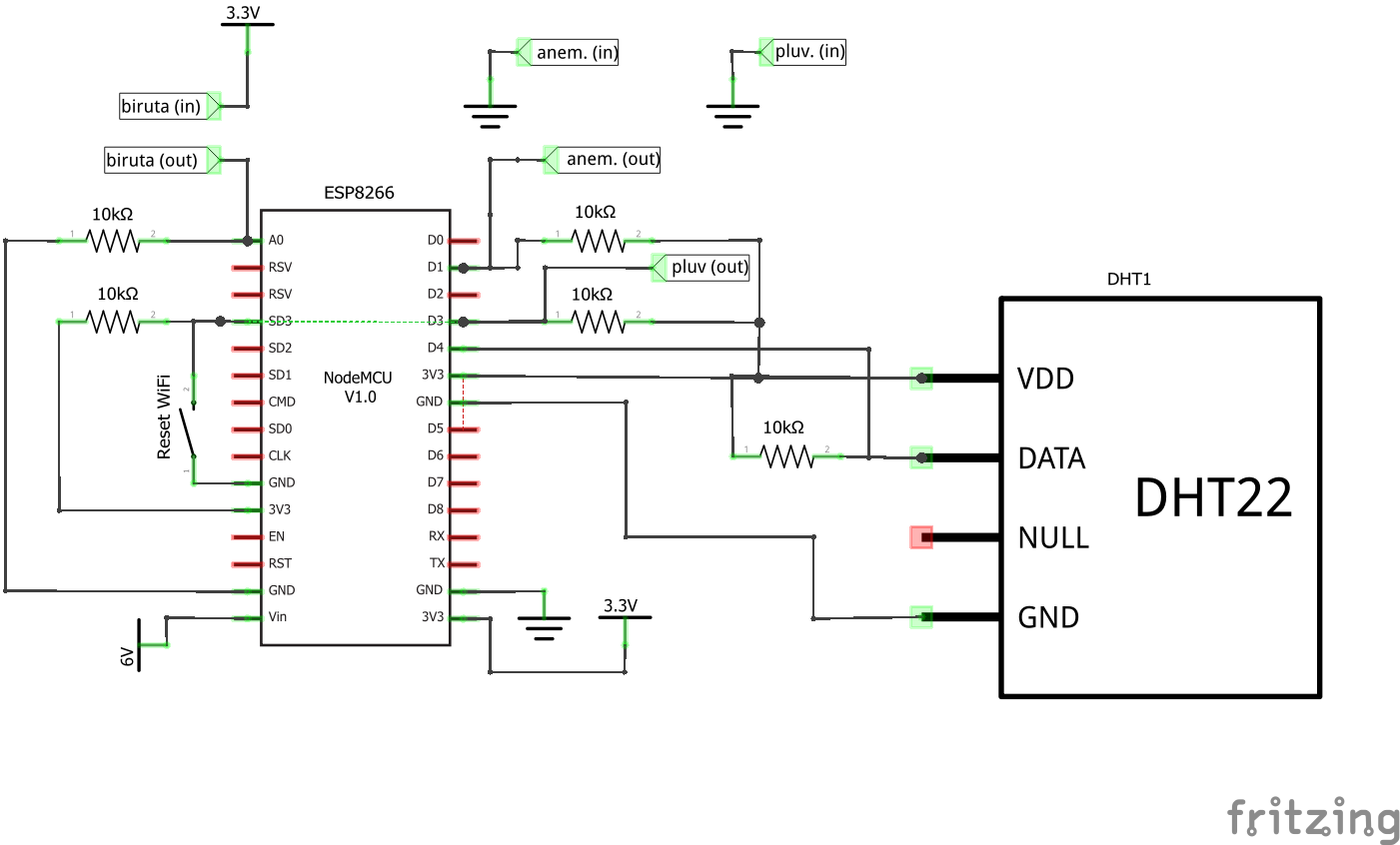
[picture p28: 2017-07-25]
Esquema eletrico/nodemcu v2_Esquemático.png
